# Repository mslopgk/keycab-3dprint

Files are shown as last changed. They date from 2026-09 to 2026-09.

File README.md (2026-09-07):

# keycab-3dprint

Parametric keycap modelling in Blender 5.2, driven programmatically.

## Layout

| Path | What it is |
| --- | --- |
| `tools/blender_mcp_ext/` | Blender extension exposing the `blender-mcp` socket protocol on `127.0.0.1:9876` |
| `tools/install_extension.py` | Copies the extension into Blender's user extension repo and enables it |
| `tools/serve_headless.py` | Runs the command server inside `blender --background` (no GUI, no manual Connect) |
| `tools/blender_server.ps1` | start / stop / restart / status / log for that headless server |
| `tools/blender_exec.py` | Send Python (or ask for scene info / a render) to the running Blender |
| `tools/mcp_client_test.py` | Protocol conformance + regression tests |
| `models/keycap.py` | Parametric Cherry MX 1u keycap: build, verify, export |
| `models/keycap_1u_r3.stl` | Printable output, literal millimetres |
| `renders/` | iso / front / bottom / underside previews |

## Setup, once

```powershell
python -m pip install uv                                    # provides uvx
blender --background --python tools\install_extension.py     # install the extension
claude mcp add blender -s user -e BLENDER_MCP_DISABLE_TELEMETRY=true `
  -e BLENDER_HOST=127.0.0.1 -e BLENDER_PORT=9876 -- uvx blender-mcp
```

`BLENDER_MCP_DISABLE_TELEMETRY=true` matters: upstream `blender-mcp` otherwise
uploads your prompt text and viewport screenshots to a remote endpoint
(`blender_mcp/telemetry.py`).

## Everyday use

```powershell
powershell -File tools\blender_server.ps1 start
python tools\blender_exec.py models\keycap.py     # rebuild, verify, export, render
python tools\blender_exec.py --scene-info
python tools\blender_exec.py --screenshot out.png --max-size 900
powershell -File tools\blender_server.ps1 stop
```

Restart the server after editing `tools/blender_mcp_ext/__init__.py` — the
headless entry point imports that module once at startup.

## Notes for this Blender build

Things that are specific to 5.2 here and cost real debugging time:

- **Legacy add-ons do not load.** `addon_utils.paths()` returns only
  `addons_core`; the user `scripts/addons` directory is no longer scanned. An
  add-on must ship as an extension with a `blender_manifest.toml`.
- **Only `BLENDER_EEVEE` is available** as a render engine — no Workbench, no
  Cycles. So there is no lighting-independent engine to fall back on, and
  previews have to bring their own lights.
- **`bpy.app.timers` never fire under `--background`.** Anything that relies on
  a timer to service work from another thread must pump on the main thread
  instead; that is what `serve_headless.py` does.
- **The default 0.1 m `clip_start` swallows millimetre-scale parts.** A camera
  framing an 18 mm keycap sits ~50 mm away, so the whole subject falls inside
  the near plane and renders as an empty background. The extension scales
  clipping to the subject.

## Keycap geometry

Modelled at 1 Blender unit = 1 mm, exported with `use_scene_unit=False` and
`global_scale=1.0`, so the STL carries literal millimetres.

Current parameters (all in `P` at the top of `models/keycap.py`):

| Parameter | Value | Note |
| --- | --- | --- |
| base | 18.0 × 18.0 mm | 1u spacing is 19.05 mm; the cap is undersized so neighbours don't rub |
| top plateau | 13.6 × 13.2 mm | Cherry-like R3, no front-to-back tilt |
| height | 8.6 mm | 8.55 mm after the dish |
| dish | 0.9 mm deep, R 24.65 mm | cylindrical, axis along X, so it scoops front-to-back |
| side wall | 1.35 mm | |
| roof | 1.5 mm | held constant under the dish, measured at three points |
| stem | ⌀5.5 mm | |
| MX cross | 4.1 × 1.35 mm, 4.0 mm deep | 1.30 grips hard but splits brittle filament; 1.40 goes loose |
| ribs | 4 × 1.0 mm, z 3.6 → 5.8 | start above the switch's top housing so they can't collide |

### Verification the build script performs

- watertight (no non-manifold edges, no loose verts) and normals outward
- roof thickness by ray-cast at three points clear of the stem and ribs
- ASCII cross-sections at z = 0.4 / 2.0 / 5.0 / 7.2 mm, which is the only way to
  confirm the cross socket and ribs — the cavity is unlit and invisible in a render
- the exported STL is re-read and its bounding box reported, to catch unit slips

A run that is not watertight still writes the STL for inspection but reports
`VERDICT: NOT PRINTABLE`.

### Not yet decided

Print orientation, tolerance for your specific printer/filament, row profile
(everything here is R3-ish and untilted), legends, and multi-unit sizes
(2u, shift, spacebar).

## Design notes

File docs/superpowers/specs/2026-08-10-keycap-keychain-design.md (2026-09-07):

# Keycap keychain with a mounted MX switch — design

Date: 2026-08-10
Status: approved, ready for implementation planning

## Goal

A keychain built around a real MX-compatible switch, with the existing
`models/keycap.py` keycap on top. The switch clicks, because the switch is
retained the way a keyboard retains it rather than glued into a shell.

## Decisions

Three questions were settled with the user up front. Each is recorded with the
option chosen, because they constrain everything downstream.

| Question | Chosen |
| --- | --- |
| Housing silhouette | Closed box — switch pins fully enclosed, nothing to snag in a pocket |
| Switch retention | Two pieces: MX latch retention on a 1.5 mm plate + removable snap-on bottom cap |
| Keyring attachment | Lug on one side with a 4.0 mm round hole |

Rejected and why:

- **Open plate frame** (bare 1.5 mm plate, no walls) — most keyboard-like, fastest
  to print, but leaves the pins exposed.
- **Press-fit pocket** (grip the 15.6 mm body, ignore the latches) — no tolerance
  headroom; 0.1 mm out and it either will not enter or does not hold.
- **One-piece closed box** — sturdiest and a single print, but with the bottom
  closed the latches cannot be reached, so the switch is in permanently.
- **Corner through-hole** / **strap slot** for the keyring — more compact, but a
  split ring in a corner hole rubs the keycap, and a strap slot cannot take a
  split ring at all.

## Parts

### A. Housing

| Parameter | Value | Note |
| --- | --- | --- |
| body footprint | 19.0 × 19.0 mm | pocket 15.8 + 2 × 1.6 wall |
| footprint incl. lug | 24.5 × 19.0 mm | |
| height | 11.0 mm | plate 1.5 + pocket 9.5 |
| top plate thickness | 1.5 mm | what the MX latches grab |
| plate opening | 14.0 × 14.0 mm, corner R0.5 | standard MX plate cutout |
| inner pocket | 15.8 × 15.8 mm | switch body 15.6 + 0.1 per side |
| pocket depth | 9.5 mm | below the plate underside |
| wall thickness | 1.6 mm | |
| latch relief | 1.0 mm deep groove below the opening, on **all four** sides | space for the latches to flex, whichever way the switch is rotated |
| lug | flat tab, 5.5 mm protrusion, 7.0 mm wide, 3.0 mm thick | see hole axis below |
| lug hole | 4.0 mm diameter, axis **vertical** (parallel to the box height), centre 2.0 mm out from the body face, 1.5 mm material around it | |

### Lug hole axis

Vertical, i.e. punched through the flat face of the tab rather than through its
edge. Two consequences, both wanted:

- Printed plate-down, a vertical hole needs no bridging. A horizontal hole would
  have to bridge across its own top.
- The keycap faces up when the keychain lies flat, instead of sideways.

The tab is deliberately offset to one side of the body, so the split ring never
touches the keycap. The assembly hangs slightly tilted because the centre of mass
is offset from the hole; this is accepted.

### B. Snap bottom cap

| Parameter | Value |
| --- | --- |
| plate | 19.0 × 19.0 × 1.2 mm, sits under the housing (assembled height 12.2 mm) |
| snap tongues | 4, one per side, 0.8 mm thick, rising into the pocket |
| undercut on housing inner wall | 0.6 mm, positioned 1.5 mm above the housing's bottom face |

### No individual pin holes

The pocket floor is flat and unbroken. The exact coordinates of the 5-pin
plastic posts and the metal pins are **not** reliably known here, and a hole
drilled at a wrong coordinate makes the part scrap. A generous flat pocket
accepts 3-pin and 5-pin switches alike without depending on those coordinates,
which also means one housing covers both switch types.

## Click travel

Nothing rises above plate level: the top face is a flat 19 × 19 plate with a
single 14 mm hole. The 18 mm keycap descends onto it unobstructed.

The argument for full 4 mm travel is structural, not arithmetic — the switch sits
in a standard 1.5 mm plate cutout, so its height relative to the plate is
identical to a keyboard's. No absolute stem or housing heights need to be known
or matched.

## Open tolerances, and how they get closed

Two values cannot be settled from specification alone:

1. **Effective plate thickness.** At a 0.28 mm layer height, a nominal 1.5 mm
   plate quantises to whatever the slicer rounds it to.
2. **Effective opening size.** Print shrinkage and extrusion width shift the
   14.0 mm cutout by an unknown fraction of a tenth.

Both are resolved empirically before the housing is printed:

**Coupon 1 — plate thickness.** One flat tile, 20 × 60 × 1.6 mm, three 20 × 20 mm
cells with plate thickness 1.4 / 1.5 / 1.6 mm at a fixed 14.0 mm opening, each
cell embossed with its thickness. Print flat, no support, roughly 4 minutes. The
cell where the switch latches with a clean click sets `plate_thickness`.

**Coupon 2 — opening (only if needed).** If every cell in coupon 1 is uniformly
loose or uniformly tight, a second coupon varies the opening 13.9 / 14.0 / 14.1
at the best thickness.

**Snap fit** will very likely need one or two iterations. The 0.6 mm undercut is a
starting value: too loose and the cap falls off, too tight and a tongue snaps.
Dial it on a coupon rather than on the full housing.

## Verification

The build script performs the same automated checks the keycap script does, for
both parts:

- watertight (no non-manifold edges, no loose vertices) and normals outward
- plate thickness measured by ray-cast at four points clear of the opening
- ASCII cross-sections at three heights — through the plate, through the pocket,
  and near the bottom face — confirming the 14.0 opening, the 15.8 pocket and the
  1.6 wall
- lug hole diameter measured
- exported STL re-read and its bounding box reported, to catch unit slips

A run that is not watertight still writes the STL for inspection but reports
`VERDICT: NOT PRINTABLE`.

## Print plan

| Part | Orientation | Support |
| --- | --- | --- |
| housing | plate face down on the bed, pocket opening upward | none |
| bottom cap | flat | none |
| coupons | flat | none |

Housing plate-down puts the flat plate face against the bed and grows the walls
upward, so the latch relief grooves and the pocket are never overhangs.

## Out of scope

Legends on the keycap, multi-unit sizes, a switch other than MX-compatible, and
any change to the existing keycap geometry. The keycap's own open question — the
1.35 mm cross slot fit — is tracked separately against the first keycap print and
does not affect this housing.

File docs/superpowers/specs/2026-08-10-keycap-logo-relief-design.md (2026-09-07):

# Raised church-wave logo on the keycap top — design

Date: 2026-08-10
Status: approved, ready for implementation planning

## Goal

Emboss the church-wave logo on the keycap top as a real raised relief, uniform
0.5 mm proud of the dished surface, printable with the existing 0.4 mm nozzle and
no support.

Source art: `C:\Users\user\Documents\카카오톡 받은 파일\church-wave-logo-03-minimal-line.svg`
(2048 × 2048 viewBox; its metadata records it as Recraft AI output).

## What the source file actually contains

The filename says "minimal-line" but the paths are **filled**, not stroked. The
navy disc is overlaid by large white shapes that carve the mark out of it, so the
region that would be embossed — navy minus white — is a set of thin strokes.
Ten paths import:

| Path role | Identified by | Action |
| --- | --- | --- |
| Background rect | its X extent equals the widest of all paths | discard |
| Navy disc, `rgb(25,8,76)` | darkest remaining path by luma | the figure |
| 2 white shapes | max dimension ≥ 2 % of the disc span | subtract from the disc |
| 3 pale slivers, `rgb(122,115,143)` / `rgb(193,190,201)` | max dimension < 2 % of the disc span; measured 0.0006–0.0061 Blender units | discard |

The slivers are anti-aliasing residue from the generator. At keycap scale they are
a few microns across and would only inject degenerate geometry into the booleans.

**Selection is by rule, never by object name.** The importer names paths
`Curve`, `Curve.001` … in file order, which is not a contract.

## Why the logo cannot be used as drawn

Measured at 12 mm diameter, sampled at 0.05 mm and eroded by the nozzle radius:

| | as drawn | +0.15 mm | +0.25 mm |
| --- | --- | --- | --- |
| ideal area | 19.45 mm² | 37.65 mm² | 49.55 mm² |
| stroke area lost to the nozzle | 8.55 mm² (44 %) | 1.62 mm² | **0.00 mm²** |
| gap area the nozzle fills in | — | 0.46 mm² | 0.59 mm² |
| fidelity | unusable | 94.5 % | **98.8 %** |

As drawn, strokes are ~0.2 mm — half a nozzle width — and 94 % of the logo area
is thinner than 0.4 mm. The cross and the outer ring disappear entirely; only the
thick lower-left wave arc survives. Scaling cannot fix it: the plateau is
13.6 × 13.2 mm, and full fidelity would need roughly 22–25 mm.

At **+0.15 mm** the cross's horizontal arms are still dropped. At **+0.25 mm**
nothing is dropped and the red merge artefacts are confined to sharp interior
junctions being rounded off. The mark reads as a bolder weight of itself.

**Decision: 12.0 mm diameter, strokes dilated by +0.25 mm.**

Caveat to carry into implementation: the erosion used a 4-connected (diamond)
structuring element, which is contained in the disc of the same radius, so it
removes slightly less than a true disc would. The survival figures are therefore
mildly optimistic and must be confirmed on the first print.

## Why the print orientation changes

The keycap is currently printed flipped, top face on the plate. A raised logo
cannot work that way, and the reason is geometric rather than a matter of taste.

The dish is a cylinder with its axis along X, so the top surface drops only in Y.
Measured on the built mesh: rim plane `z = 8.5522`, dish centre `z = 7.7000`.
For a logo whose top is one flat plane at the rim height, the relief available is:

| position | relief |
| --- | --- |
| along X, any offset | 0.852 mm |
| y = ±3 | 0.661 mm |
| y = ±5 | 0.336 mm |
| y = ±6 | **0.111 mm** |

0.111 mm is below both the 0.28 mm layer height and the 0.20 mm first layer, so
the ring's top and bottom would vanish while its left and right stood 0.852 mm
proud — a 7.7× asymmetry.

Giving the logo a dish-parallel top instead makes the relief uniform, but that
surface sits below the bed plane once the part is flipped, which is impossible.
**Uniform relief and flipped printing are mutually exclusive.**

**Decision: print the logo variant right side up** — bottom rim and stem base on
the plate, logo uppermost.

Right side up, the only surface that would need support is the cavity ceiling,
which currently runs parallel to the dish at about 6.4° from horizontal.
**Decision: make the ceiling flat at `z = 6.2`** so it becomes a ~15 mm bridge,
which needs no support. The cost is a roof that is no longer a constant
thickness: 1.5 mm at the centre, 2.24 mm at the plateau edge. For a keychain the
extra material does not matter.

Everything else prints in its best orientation: the outer walls narrow going up
(self-supporting), the stem grows from the plate, the ribs are ~3 mm bridges, the
cross socket's roof is a trivial bridge, and the visible top surface is printed
last.

## Separate variant, not a modification

The plain keycap stays exactly as it is. The logo version is a second output.

This is not tidiness: Task 2 of `docs/superpowers/plans/2026-08-10-mx-switch-keychain.md`
uses the current STL hashes (`f567510240023cb5a7808314c5a7bf60` and
`51c9fe26924c15bf2439d854c985276d`) as its refactor regression gate. Changing the
existing outputs would break that check.

- `models/keycap_1u_r3.stl` — unchanged, flipped-print orientation, no logo
- `models/keycap_1u_r3_logo.stl` — flat ceiling, right side up, logo

The logo and the flat ceiling are enabled together by one parameter block; the
ceiling shape follows from the print orientation, which follows from the logo.

## Construction

The relief is cut from between two copies of the dish cylinder rather than
extruded to a fixed height, which is what makes the relief uniform:

```
logo_2d    = disc − white_cutters, dilated +0.25 mm, scaled to 12.0 mm
logo_prism = logo_2d extruded well past both surfaces
logo_solid = logo_prism ∩ dish_cutter − dish_cutter_raised_by_0.5mm
keycap     = keycap ∪ logo_solid
```

`dish_cutter` is the same cylinder the keycap already uses for the dish, so its
lower boundary *is* the top surface. Raising a second copy by 0.5 mm gives the
logo's top surface, parallel by construction.

Dilation: try `Curve.offset` on the composed 2D curve first and measure the
resulting stroke widths. If it does not offset the fill correctly, fall back to
rasterising at 0.02 mm and tracing contours — 20× finer than the 0.4 mm the
printer can resolve, so the faceting is invisible in the print.

## Accepted consequence: the logo crests the rim

At y = ±6 the dish surface is at 8.4416, so the logo top reaches 8.9416 — about
0.39 mm above the rim plane at 8.5522. The ring's top and bottom therefore stand
proud of the keycap's top edge, giving a medallion look from the side, and the
part's height becomes 8.94 mm instead of 8.5522 mm.

Printing right side up means this costs nothing technically; it is purely
appearance, and it is accepted. The alternative — shrinking the logo to 8 mm so it
tucks under the rim — was rejected because the stroke-width evidence was gathered
at 12 mm and would have to be redone.

## Verification

Same automated gates as the keycap, plus logo-specific ones:

- watertight (no non-manifold edges, no loose vertices) and normals outward
- relief height ray-cast at eight points spread around the logo; every one must
  read 0.5 mm ± 0.02 mm — this is the check that would have caught the flat-top
  defect
- minimum stroke width on the **final** mesh, measured by rasterising and
  eroding; must be ≥ 0.45 mm, giving margin over the 0.4 mm nozzle
- ceiling flatness: ray-cast up from inside the cavity at several points, all
  returning the same z
- roof thickness measured at the centre (expect 1.5 mm) and at the plateau edge
  (expect 2.24 mm)
- ASCII cross-section just below the top surface, showing the logo outline
- exported STL re-read; bounding box must be 18.0 × 18.0 × 8.94 mm
- top-down render for a visual check against the reference art

A run that fails watertightness or the relief-height check still writes the STL
for inspection but reports `VERDICT: NOT PRINTABLE`.

## Print settings

Right side up, no support, brim 3 mm, 0.28 mm layers, textured PEI plate at
65 °C, sliced through `tools/slice_part.ps1` from the keychain plan.

## Out of scope

Text legends, a second filament colour for the logo, any change to the plain
keycap or to the switch housing, and re-cutting the source SVG by hand.

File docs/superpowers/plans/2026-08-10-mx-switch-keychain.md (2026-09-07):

# MX Switch Keychain Implementation Plan

> **For agentic workers:** REQUIRED SUB-SKILL: Use superpowers:subagent-driven-development (recommended) or superpowers:executing-plans to implement this plan task-by-task. Steps use checkbox (`- [ ]`) syntax for tracking.

**Goal:** Build a two-piece 3D-printable closed-box housing that retains a real MX-compatible switch on a 1.5 mm plate cutout, with a keyring lug and a removable snap-on bottom cap, plus fit coupons to settle the two unknown tolerances first.

**Architecture:** Geometry helpers currently private to `models/keycap.py` get extracted into an importable `models/mxgeom.py`, then the housing, the cap, and the coupons are three build scripts on top of it. Everything runs inside a headless Blender through the existing socket server; there is no pytest, so "tests" are assertion scripts that run in Blender and exit non-zero on failure.

**Tech Stack:** Blender 5.2 `bpy`/`bmesh` (1 Blender unit == 1 mm), Python 3.12 on the host, the project's own `tools/blender_exec.py` socket client, OrcaSlicer 2.4.2 portable CLI, Bambu Lab A1 mini over LAN.

## Global Constraints

- Model at **1 Blender unit == 1 mm**. Export STL with `global_scale=1.0` and `use_scene_unit=False`.
- Every exported part must be **watertight** (zero non-manifold edges, zero loose vertices) with **outward normals** (`signed_volume > 0`). A part failing this still exports for inspection but the script must report `VERDICT: NOT PRINTABLE`.
- **No individual pin holes** in the pocket floor. The floor is flat and unbroken.
- Housing dimensions, verbatim from the spec: body `19.0 × 19.0 mm`; footprint incl. lug `24.5 × 19.0 mm`; height `11.0 mm`; plate thickness `1.5 mm`; plate opening `14.0 × 14.0 mm` corner `R0.5`; pocket `15.8 × 15.8 mm`; pocket depth `9.5 mm`; wall `1.6 mm`; latch relief `1.0 mm` deep on **all four** sides; lug tab `5.5 mm` protrusion × `7.0 mm` wide × `3.0 mm` thick; lug hole `4.0 mm` diameter, **vertical axis**, centre `2.0 mm` out from the body face, `1.5 mm` material around it.
- Bottom cap, verbatim from the spec: `19.0 × 19.0 × 1.2 mm` plate sitting **under** the housing (assembled height `12.2 mm`); `4` snap tongues, one per side, `0.8 mm` thick; housing inner-wall undercut `0.6 mm`, positioned `1.5 mm` above the housing's bottom face.
- Coupon 1, verbatim from the spec: one flat tile `20 × 60 × 1.6 mm`, three `20 × 20 mm` cells, plate thickness `1.4 / 1.5 / 1.6 mm`, opening fixed at `14.0 mm`, each cell embossed with its thickness.
- Print orientation: housing **plate face down**, cap **flat**, coupons **flat**. No support on any part.
- Do not delete or overwrite anything on the printer's SD card.

---

### Task 1: Give Blender-side scripts a `__file__` so they can import siblings

The addon's `execute_code` builds its namespace with `__name__` but no `__file__` (`tools/blender_mcp_ext/__init__.py:140-146`). A script sent through the socket therefore cannot locate its own directory, so `models/switch_housing.py` cannot `import mxgeom`. Fix it host-side in the client by prepending a preamble, which keeps the wire protocol unchanged and needs no addon edit or server restart.

**Files:**
- Modify: `tools/blender_exec.py` (the `main()` branch that reads a script file)
- Create: `tests/blender/test_script_context.py`

**Interfaces:**
- Consumes: nothing.
- Produces: a guarantee that any file executed via `python tools/blender_exec.py <path>` sees `__file__` set to the script's absolute path, and that `os.path.dirname(__file__)` is on `sys.path`.

- [ ] **Step 1: Write the failing test**

Create `tests/blender/test_script_context.py`:

```python
"""Runs inside Blender. Exits non-zero if the script context is missing."""

import os
import sys

failures = []

def check(label, condition, detail=""):
    print(f"{'PASS' if condition else 'FAIL'}  {label}" + (f" -- {detail}" if detail else ""))
    if not condition:
        failures.append(label)

check("__file__ is defined", "__file__" in globals(), repr(globals().get("__file__")))

path = globals().get("__file__", "")
check("__file__ is absolute", bool(path) and os.path.isabs(path), path)
check("__file__ basename matches", os.path.basename(path) == "test_script_context.py", path)
check("__file__ exists on disk", bool(path) and os.path.exists(path), path)
check("own directory is importable", os.path.dirname(path) in sys.path, os.path.dirname(path))

print(f"\n{'ALL CHECKS PASSED' if not failures else str(len(failures)) + ' FAILED: ' + str(failures)}")
if failures:
    raise SystemExit(1)
```

- [ ] **Step 2: Run test to verify it fails**

```bash
powershell -File tools/blender_server.ps1 start
python tools/blender_exec.py tests/blender/test_script_context.py
```

Expected: `FAIL  __file__ is defined -- None` and the remaining four checks also FAIL, because `blender_exec.py` currently sends only the file's bytes.

- [ ] **Step 3: Write minimal implementation**

In `tools/blender_exec.py`, replace the branch that reads a script from disk:

```python
        elif args.script:
            with open(args.script, "r", encoding="utf-8") as handle:
                code = handle.read()
```

with:

```python
        elif args.script:
            with open(args.script, "r", encoding="utf-8") as handle:
                code = handle.read()
            # execute_code has no notion of a file, so the script cannot find its
            # own directory and cannot import a sibling module. Supply both.
            script_path = os.path.abspath(args.script)
            preamble = (
                "import os, sys\n"
                f"__file__ = {script_path!r}\n"
                f"_d = os.path.dirname({script_path!r})\n"
                "sys.path.insert(0, _d) if _d not in sys.path else None\n"
                "del _d\n"
            )
            code = preamble + code
```

- [ ] **Step 4: Run test to verify it passes**

```bash
python tools/blender_exec.py tests/blender/test_script_context.py
```

Expected: five `PASS` lines then `ALL CHECKS PASSED`, exit code 0.

- [ ] **Step 5: Confirm nothing regressed for inline code and the existing suite**

```bash
python tools/blender_exec.py -c "print('inline still works')"
python tools/mcp_client_test.py
```

Expected: `inline still works`; then `ALL CHECKS PASSED` from the protocol suite. The preamble is only added on the file branch, so `-c` is untouched.

- [ ] **Step 6: Commit**

```bash
git add tools/blender_exec.py tests/blender/test_script_context.py
git commit -m "feat: give Blender-side scripts __file__ and an importable directory"
```

---

### Task 2: Extract shared geometry into `models/mxgeom.py`

`models/keycap.py` defines every helper the housing needs but keeps them file-local, and it calls `main()` at module level, so importing it would rebuild and re-export the keycap. Extract the reusable half into a module that has no side effects at import.

**Files:**
- Create: `models/mxgeom.py`
- Modify: `models/keycap.py` (delete the extracted definitions, import them instead)
- Create: `tests/blender/test_mxgeom.py`

**Interfaces:**
- Consumes: Task 1's `sys.path` injection, so `import mxgeom` resolves from `models/`.
- Produces, all in `mxgeom`, signatures unchanged from their current definitions in `keycap.py`:
  - `rounded_rect(width, depth, radius, segments) -> list[tuple[float, float]]`
  - `make_loft(name, bottom_outline, z0, top_outline, z1) -> bpy.types.Object`
  - `make_box(name, size, location) -> bpy.types.Object`
  - `make_cylinder(name, radius, depth, location, segments, axis="Z") -> bpy.types.Object`
  - `boolean(target, tool, operation, keep_tool=False) -> bpy.types.Object`
  - `duplicate(obj, name) -> bpy.types.Object`
  - `bevel_top_rim(obj, z_top, offset, segments) -> int`
  - `mesh_report(obj) -> dict`
  - `reset_scene() -> None`
  - `point_inside(obj, point) -> bool`
  - `export_stl(obj, path) -> str`
  - `verify_stl_millimetres(path) -> dict`
  - And one new helper, generalised from `keycap.cross_sections` so it no longer takes the keycap's `P` dict:
    `cross_sections(obj, half_extent, heights, step=0.5) -> dict[str, list[str]]`

- [ ] **Step 1: Write the failing test**

Create `tests/blender/test_mxgeom.py`:

```python
"""Runs inside Blender. Checks the extracted helpers behave as before."""

import mxgeom

failures = []

def check(label, condition, detail=""):
    print(f"{'PASS' if condition else 'FAIL'}  {label}" + (f" -- {detail}" if detail else ""))
    if not condition:
        failures.append(label)

mxgeom.reset_scene()

# rounded_rect: 4 corners * (segments + 1) points, all inside the half extents.
pts = mxgeom.rounded_rect(19.0, 19.0, 1.0, 8)
check("rounded_rect point count", len(pts) == 4 * 9, str(len(pts)))
check("rounded_rect stays in bounds",
      max(abs(x) for x, _ in pts) <= 9.5 + 1e-6 and max(abs(y) for _, y in pts) <= 9.5 + 1e-6)

# make_box: a 19 x 19 x 1.2 plate centred at z = 0.6 spans z 0..1.2.
box = mxgeom.make_box("T_Box", (19.0, 19.0, 1.2), (0.0, 0.0, 0.6))
check("make_box dimensions", [round(v, 4) for v in box.dimensions] == [19.0, 19.0, 1.2],
      str([round(v, 4) for v in box.dimensions]))
report = mxgeom.mesh_report(box)
check("make_box watertight", report["watertight"], str(report))
check("make_box normals outward", report["normals_outward"], str(report))
check("make_box volume", abs(report["signed_volume_mm3"] - 19.0 * 19.0 * 1.2) < 1e-3,
      str(report["signed_volume_mm3"]))

# point_inside: centre is solid, a point outside the slab is not.
check("point_inside centre", mxgeom.point_inside(box, (0.0, 0.0, 0.6)) is True)
check("point_inside above", mxgeom.point_inside(box, (0.0, 0.0, 5.0)) is False)

# boolean DIFFERENCE punches a hole that point_inside can see.
tool = mxgeom.make_cylinder("T_Cut", 2.0, 10.0, (0.0, 0.0, 0.6), 48)
mxgeom.boolean(box, tool, "DIFFERENCE")
check("boolean cut removes centre", mxgeom.point_inside(box, (0.0, 0.0, 0.6)) is False)
check("boolean cut keeps edge", mxgeom.point_inside(box, (8.0, 8.0, 0.6)) is True)
check("boolean result watertight", mxgeom.mesh_report(box)["watertight"])

# cross_sections takes a half extent now, not the keycap parameter dict.
sections = mxgeom.cross_sections(box, 10.0, heights=(0.6,), step=1.0)
rows = sections["z=0.6"]
check("cross_sections row count", len(rows) == 21, str(len(rows)))
check("cross_sections centre is air", rows[len(rows) // 2][len(rows) // 2] == ".",
      rows[len(rows) // 2])

print(f"\n{'ALL CHECKS PASSED' if not failures else str(len(failures)) + ' FAILED: ' + str(failures)}")
if failures:
    raise SystemExit(1)
```

- [ ] **Step 2: Run test to verify it fails**

```bash
python tools/blender_exec.py tests/blender/test_mxgeom.py
```

Expected: FAIL with `ModuleNotFoundError: No module named 'mxgeom'`.

- [ ] **Step 3: Create `models/mxgeom.py`**

Move — do not copy — these definitions out of `models/keycap.py` into a new `models/mxgeom.py`, keeping their bodies byte-identical: `rounded_rect`, `make_loft`, `bevel_top_rim`, `make_box`, `make_cylinder`, `boolean`, `duplicate`, `mesh_report`, `reset_scene`, `point_inside`, `export_stl`, `verify_stl_millimetres`. Give the module this header and imports, and no module-level side effects:

```python
"""Shared geometry and verification helpers for the keycab-3dprint models.

Modelled at 1 Blender unit == 1 mm throughout. Import-safe: defining anything
here must never touch the scene, so build scripts can import it freely.
"""

import math
import os
import struct

import bmesh
import bpy
import mathutils
```

Then add the generalised `cross_sections`, replacing the keycap-specific one:

```python
def cross_sections(obj, half_extent, heights, step=0.5):
    """ASCII slices through the solid, '#' for material and '.' for air.

    Takes an explicit half extent rather than a parameter dict so any part can
    use it. Rows print with +Y at the top and +X to the right.
    """
    coords = []
    value = -half_extent
    while value <= half_extent + 1e-9:
        coords.append(round(value, 3))
        value += step

    sections = {}
    for z in heights:
        rows = []
        for y in reversed(coords):
            rows.append("".join(
                "#" if point_inside(obj, (x, y, z)) else "."
                for x in coords
            ))
        sections[f"z={z}"] = rows
    return sections
```

- [ ] **Step 4: Repoint `models/keycap.py` at the module**

Replace `keycap.py`'s now-deleted definitions with an import, and delete its local `cross_sections`:

```python
import mxgeom
from mxgeom import (
    bevel_top_rim, boolean, cross_sections, duplicate, export_stl, make_box,
    make_cylinder, make_loft, mesh_report, point_inside, reset_scene,
    rounded_rect, verify_stl_millimetres,
)
```

Update the one call site that passed the parameter dict. In `main()`, change:

```python
    sections = cross_sections(keycap, P, heights=(0.4, 2.0, 5.0, 7.2))
```

to:

```python
    sections = cross_sections(keycap, P["base_width"] / 2.0 + 0.25,
                              heights=(0.4, 2.0, 5.0, 7.2))
```

Leave `dish_radius`, `build_keycap`, `measure_top_thickness`, `render_views`, `main`, `P` and `REPORT` in `keycap.py` — they are keycap-specific.

- [ ] **Step 5: Run the helper test to verify it passes**

```bash
python tools/blender_exec.py tests/blender/test_mxgeom.py
```

Expected: every check `PASS`, then `ALL CHECKS PASSED`, exit code 0.

- [ ] **Step 6: Prove the keycap is byte-identical after the refactor**

The extraction must not change geometry, so re-running the keycap build must reproduce the exact same STL.

```bash
python tools/blender_exec.py models/keycap.py
md5sum models/keycap_1u_r3.stl
```

Expected: `KEYCAP_REPORT_START` … `"VERDICT": "printable"`, `non_manifold_edges: 0`, and the hash exactly `f567510240023cb5a7808314c5a7bf60` (45184 bytes). Then re-run the print-orientation export and check its hash too:

```bash
"/c/Program Files/Blender Foundation/Blender 5.2/blender.exe" --background models/keycap_1u_r3.blend --python models/export_printready.py
md5sum models/keycap_1u_r3_printready.stl
```

Expected: `51c9fe26924c15bf2439d854c985276d` (45184 bytes). **If either hash differs, the extraction changed behaviour — stop and diff the moved functions rather than accepting the new hash.**

- [ ] **Step 7: Commit**

```bash
git add models/mxgeom.py models/keycap.py tests/blender/test_mxgeom.py
git commit -m "refactor: extract shared geometry helpers into models/mxgeom.py"
```

---

### Task 3: Housing body — plate, opening and pocket

Build the housing's core solid: a 19 × 19 × 11 block, a 14 × 14 opening through the 1.5 mm top plate, and a 15.8 × 15.8 × 9.5 pocket open at the bottom. Lug and latch relief come in Task 4; the cap comes in Task 5.

**Files:**
- Create: `models/switch_housing.py`
- Create: `tests/blender/test_housing_body.py`

**Interfaces:**
- Consumes: `mxgeom.rounded_rect`, `make_box`, `boolean`, `mesh_report`, `reset_scene`, `point_inside`, `cross_sections`, `export_stl`, `verify_stl_millimetres`.
- Produces:
  - `models/switch_housing.py` module-level `H` dict holding every dimension by the spec's names: `body_width`, `body_depth`, `height`, `plate_thickness`, `opening`, `opening_corner_r`, `pocket`, `pocket_depth`, `wall`, `latch_relief_depth`, `lug_protrusion`, `lug_width`, `lug_thickness`, `lug_hole_diameter`, `lug_hole_offset`, `cap_thickness`, `cap_tongue_thickness`, `undercut_depth`, `undercut_z`, `corner_segments`.
  - `build_housing(h) -> bpy.types.Object` named `Switch_Housing`.
  - `housing_report(obj, h) -> dict` with keys `dimensions_mm`, `mesh`, `plate_thickness_probe`, `opening_probe`, `pocket_probe`, `VERDICT`.

- [ ] **Step 1: Write the failing test**

Create `tests/blender/test_housing_body.py`:

```python
"""Runs inside Blender. Verifies the housing's plate, opening and pocket."""

import mxgeom
import switch_housing

failures = []

def check(label, condition, detail=""):
    print(f"{'PASS' if condition else 'FAIL'}  {label}" + (f" -- {detail}" if detail else ""))
    if not condition:
        failures.append(label)

mxgeom.reset_scene()
h = dict(switch_housing.H)
# Task 3 builds the core solid only; lug and relief are Task 4.
h["lug_protrusion"] = 0.0
h["latch_relief_depth"] = 0.0
obj = switch_housing.build_housing(h)

dims = [round(v, 4) for v in obj.dimensions]
check("footprint without lug is 19 x 19", dims[0] == 19.0 and dims[1] == 19.0, str(dims))
check("height is 11.0", dims[2] == 11.0, str(dims))

report = mxgeom.mesh_report(obj)
check("watertight", report["watertight"], str(report))
check("normals outward", report["normals_outward"], str(report))

plate_top = h["height"]                      # 11.0
plate_bottom = h["height"] - h["plate_thickness"]   # 9.5

# Plate: solid at its own level away from the opening, air inside the opening.
check("plate is solid at the edge",
      mxgeom.point_inside(obj, (8.5, 8.5, plate_top - 0.5)) is True)
check("opening is air at plate level",
      mxgeom.point_inside(obj, (0.0, 0.0, plate_top - 0.5)) is False)
check("opening is 14 wide: inside at 6.8",
      mxgeom.point_inside(obj, (6.8, 0.0, plate_top - 0.5)) is False)
check("opening is 14 wide: material at 7.2",
      mxgeom.point_inside(obj, (7.2, 0.0, plate_top - 0.5)) is True)

# Pocket: air in the middle, wall material outside 15.8/2 = 7.9.
check("pocket is air", mxgeom.point_inside(obj, (0.0, 0.0, 5.0)) is False)
check("pocket is 15.8 wide: inside at 7.7",
      mxgeom.point_inside(obj, (7.7, 0.0, 5.0)) is False)
check("wall is material at 8.5", mxgeom.point_inside(obj, (8.5, 0.0, 5.0)) is True)

# body_width, pocket and wall must agree, or the wall thickness is a fiction.
bad = dict(h)
bad["pocket"] = 16.2          # would imply a 1.4 wall, not 1.6
raised = False
try:
    switch_housing.build_housing(bad)
except ValueError:
    raised = True
check("inconsistent wall raises ValueError", raised)

# Bottom face must be open, not skinned over.
check("bottom is open", mxgeom.point_inside(obj, (0.0, 0.0, 0.2)) is False)

# Ray-cast the plate thickness at a point clear of the opening.
probe = switch_housing.housing_report(obj, h)["plate_thickness_probe"]
check("plate measures 1.5 thick",
      any(abs(v - 1.5) < 0.02 for v in probe.values() if isinstance(v, float)),
      str(probe))

print(f"\n{'ALL CHECKS PASSED' if not failures else str(len(failures)) + ' FAILED: ' + str(failures)}")
if failures:
    raise SystemExit(1)
```

- [ ] **Step 2: Run test to verify it fails**

```bash
python tools/blender_exec.py tests/blender/test_housing_body.py
```

Expected: FAIL with `ModuleNotFoundError: No module named 'switch_housing'`.

- [ ] **Step 3: Write minimal implementation**

Create `models/switch_housing.py`:

```python
"""Two-piece closed-box housing that retains an MX-compatible switch.

Spec: docs/superpowers/specs/2026-08-10-keycap-keychain-design.md

Modelled at 1 Blender unit == 1 mm. The switch is held the way a keyboard holds
it -- latches gripping the underside of a 1.5 mm plate -- so click travel matches
a keyboard by construction rather than by matching absolute stem heights.
"""

import json
import os

import bmesh
import bpy
import mathutils

import mxgeom
from mxgeom import (
    boolean, cross_sections, export_stl, make_box, make_cylinder, make_loft,
    mesh_report, point_inside, reset_scene, rounded_rect, verify_stl_millimetres,
)

H = {
    "body_width": 19.0,
    "body_depth": 19.0,
    "height": 11.0,
    "plate_thickness": 1.5,
    "opening": 14.0,
    "opening_corner_r": 0.5,
    "pocket": 15.8,
    "pocket_depth": 9.5,
    "wall": 1.6,
    "latch_relief_depth": 1.0,
    "lug_protrusion": 5.5,
    "lug_width": 7.0,
    "lug_thickness": 3.0,
    "lug_hole_diameter": 4.0,
    "lug_hole_offset": 2.0,
    "cap_thickness": 1.2,
    "cap_tongue_thickness": 0.8,
    "undercut_depth": 0.6,
    "undercut_z": 1.5,
    "corner_segments": 8,
}

def build_housing(h):
    """Core solid: block, plate opening, pocket. Lug/relief handled by Task 4."""
    # body_width, pocket and wall are three numbers describing two independent
    # dimensions, so they can silently disagree. Fail loudly instead.
    derived_wall = (h["body_width"] - h["pocket"]) / 2.0
    if abs(derived_wall - h["wall"]) > 1e-6:
        raise ValueError(
            f"wall mismatch: body_width {h['body_width']} - pocket {h['pocket']} "
            f"implies a {derived_wall} wall, but wall is set to {h['wall']}"
        )

    body = make_box(
        "Switch_Housing",
        (h["body_width"], h["body_depth"], h["height"]),
        (0.0, 0.0, h["height"] / 2.0),
    )

    # Pocket, open at the bottom. Extends below z=0 so the underside is genuinely
    # open rather than skinned, the same trick the keycap cavity uses.
    pocket_top = h["height"] - h["plate_thickness"]
    pocket = make_box(
        "Pocket",
        (h["pocket"], h["pocket"], h["pocket_depth"] + 2.0),
        (0.0, 0.0, pocket_top - (h["pocket_depth"] + 2.0) / 2.0 + 1.0),
    )
    boolean(body, pocket, "DIFFERENCE")

    # Plate opening: rounded-square prism through the plate only, overshooting
    # both faces so no coplanar faces meet the plate surfaces.
    outline = rounded_rect(h["opening"], h["opening"], h["opening_corner_r"],
                           h["corner_segments"])
    opening = make_loft("Opening", outline, pocket_top - 1.0, outline, h["height"] + 1.0)
    boolean(body, opening, "DIFFERENCE")

    body.name = "Switch_Housing"
    body.data.name = "Switch_Housing"
    return body

def measure_plate_thickness(obj, h):
    """Ray-cast down through the plate at four points clear of the opening."""
    results = {}
    for label, x, y in (("front_left", -8.2, -8.2), ("front_right", 8.2, -8.2),
                        ("back_left", -8.2, 8.2), ("back_right", 8.2, 8.2)):
        origin = mathutils.Vector((x, y, h["height"] + 5.0))
        direction = mathutils.Vector((0.0, 0.0, -1.0))
        hits = []
        cursor = origin.copy()
        for _ in range(6):
            hit, location, _n, _i = obj.ray_cast(cursor, direction)
            if not hit:
                break
            hits.append(round(location.z, 4))
            cursor = location + direction * 1e-4
        results[f"{label}_hits"] = hits
        if len(hits) >= 2:
            results[label] = round(hits[0] - hits[1], 4)
    return results

def _span(obj, z, axis):
    """Width of the air gap through the centre at height z, sampled at 0.05mm."""
    step = 0.05
    limit = 12.0
    positive = 0.0
    value = 0.0
    while value <= limit:
        point = (value, 0.0, z) if axis == "x" else (0.0, value, z)
        if point_inside(obj, point):
            break
        positive = value
        value += step
    return round(positive * 2.0, 3)

def housing_report(obj, h):
    plate_top = h["height"]
    report = {
        "dimensions_mm": [round(v, 4) for v in obj.dimensions],
        "mesh": mesh_report(obj),
        "plate_thickness_probe": measure_plate_thickness(obj, h),
        "opening_probe": {
            "x_span_mm": _span(obj, plate_top - h["plate_thickness"] / 2.0, "x"),
            "y_span_mm": _span(obj, plate_top - h["plate_thickness"] / 2.0, "y"),
        },
        "pocket_probe": {
            "x_span_mm": _span(obj, h["pocket_depth"] / 2.0, "x"),
            "y_span_mm": _span(obj, h["pocket_depth"] / 2.0, "y"),
        },
    }
    mesh = report["mesh"]
    if not mesh["watertight"]:
        report["VERDICT"] = "NOT PRINTABLE - mesh is not watertight"
    elif not mesh["normals_outward"]:
        report["VERDICT"] = "NOT PRINTABLE - normals point inward"
    else:
        report["VERDICT"] = "printable"
    return report

def main():
    project = os.environ.get(
        "KEYCAB_PROJECT", r"C:\Users\user\orca\projects\keycab-3dprint"
    )
    reset_scene()
    scene = bpy.context.scene
    scene.unit_settings.system = "METRIC"
    scene.unit_settings.scale_length = 0.001
    scene.unit_settings.length_unit = "MILLIMETERS"

    housing = build_housing(H)
    report = housing_report(housing, H)
    report["parameters"] = H

    stl = os.path.join(project, "models", "switch_housing.stl")
    export_stl(housing, stl)
    report["stl"] = verify_stl_millimetres(stl)

    print("HOUSING_REPORT_START")
    print(json.dumps(report, indent=2))
    print("HOUSING_REPORT_END")

    sections = cross_sections(housing, H["body_width"] / 2.0 + 0.25,
                              heights=(0.5, 5.0, 10.2))
    print("\nCROSS SECTIONS  ('#' = plastic, '.' = air, 0.5mm grid, +Y up, +X right)")
    for label, rows in sections.items():
        print(f"\n--- {label} mm ---")
        for row in rows:
            print("   " + row)

if __name__ == "__blender_mcp__":
    main()
```

- [ ] **Step 4: Run test to verify it passes**

```bash
python tools/blender_exec.py tests/blender/test_housing_body.py
```

Expected: every check `PASS`, then `ALL CHECKS PASSED`.

If `watertight` fails, the cause is almost certainly a coplanar face where the pocket or opening cutter lands exactly on a housing surface — the same failure mode that produced 10 non-manifold edges in the keycap. Widen the offending cutter's overshoot; do not "fix" it by ignoring the check.

- [ ] **Step 5: Run the full build and read the cross-sections**

```bash
python tools/blender_exec.py models/switch_housing.py
```

Expected: `"VERDICT": "printable"`, `non_manifold_edges: 0`, `opening_probe` spans ≈ `14.0`, `pocket_probe` spans ≈ `15.8`, `stl.size_mm` ≈ `[19.0, 19.0, 11.0]`. The `z=10.2` section shows a 14 mm square hole in a solid plate; `z=5.0` shows a 15.8 mm pocket ringed by 1.6 mm wall; `z=0.5` looks the same as `z=5.0`.

- [ ] **Step 6: Commit**

```bash
git add models/switch_housing.py tests/blender/test_housing_body.py
git commit -m "feat: housing body with 1.5mm plate, 14mm MX opening and 15.8mm pocket"
```

---

### Task 4: Latch relief on all four sides, and the keyring lug

**Files:**
- Modify: `models/switch_housing.py` (extend `build_housing`)
- Create: `tests/blender/test_housing_lug_relief.py`

**Interfaces:**
- Consumes: Task 3's `build_housing(h)`, `H`, `housing_report(obj, h)`.
- Produces: `build_housing` now honours `h["latch_relief_depth"]` and `h["lug_protrusion"]`; `housing_report` gains a `lug_hole_probe` key with `diameter_mm`.

- [ ] **Step 1: Write the failing test**

Create `tests/blender/test_housing_lug_relief.py`:

```python
"""Runs inside Blender. Verifies latch relief grooves and the keyring lug."""

import mxgeom
import switch_housing

failures = []

def check(label, condition, detail=""):
    print(f"{'PASS' if condition else 'FAIL'}  {label}" + (f" -- {detail}" if detail else ""))
    if not condition:
        failures.append(label)

mxgeom.reset_scene()
h = dict(switch_housing.H)
obj = switch_housing.build_housing(h)

dims = [round(v, 4) for v in obj.dimensions]
check("footprint with lug is 24.5 x 19", dims[0] == 24.5 and dims[1] == 19.0, str(dims))
check("height still 11.0", dims[2] == 11.0, str(dims))

report = mxgeom.mesh_report(obj)
check("watertight", report["watertight"], str(report))
check("normals outward", report["normals_outward"], str(report))

plate_bottom = h["height"] - h["plate_thickness"]     # 9.5
relief_z = plate_bottom - h["latch_relief_depth"] / 2.0   # 9.0

# Relief widens the opening below the plate on all four sides, so a point that
# is material at plate level is air one millimetre lower.
for label, x, y in (("+X", 7.2, 0.0), ("-X", -7.2, 0.0),
                    ("+Y", 0.0, 7.2), ("-Y", 0.0, -7.2)):
    check(f"relief present on {label}",
          mxgeom.point_inside(obj, (x, y, h["height"] - 0.5)) is True
          and mxgeom.point_inside(obj, (x, y, relief_z)) is False,
          f"plate={mxgeom.point_inside(obj, (x, y, h['height'] - 0.5))} "
          f"relief={mxgeom.point_inside(obj, (x, y, relief_z))}")

check("relief does not breach the wall",
      mxgeom.point_inside(obj, (8.6, 0.0, relief_z)) is True)

# Lug sits on -X, centred on the body height, hole axis vertical.
lug_x = -(h["body_width"] / 2.0 + h["lug_hole_offset"])   # -11.5
lug_z = h["height"] / 2.0                                  # 5.5
check("lug material exists", mxgeom.point_inside(obj, (lug_x, 3.0, lug_z)) is True)
check("lug hole is air at its centre",
      mxgeom.point_inside(obj, (lug_x, 0.0, lug_z)) is False)
check("lug hole is 4mm: air at 1.8 from centre",
      mxgeom.point_inside(obj, (lug_x, 1.8, lug_z)) is False)
check("lug hole is 4mm: material at 2.2 from centre",
      mxgeom.point_inside(obj, (lug_x, 2.2, lug_z)) is True)

# Vertical axis: the hole is air all the way through the tab's 3mm thickness,
# and solid above and below it.
check("hole runs vertically through the tab",
      mxgeom.point_inside(obj, (lug_x, 0.0, lug_z + 1.0)) is False
      and mxgeom.point_inside(obj, (lug_x, 0.0, lug_z - 1.0)) is False)
check("tab has material above the hole",
      mxgeom.point_inside(obj, (lug_x, 3.0, lug_z + 1.0)) is True)

probe = switch_housing.housing_report(obj, h)["lug_hole_probe"]
check("measured hole diameter is 4.0",
      abs(probe["diameter_mm"] - 4.0) < 0.15, str(probe))

print(f"\n{'ALL CHECKS PASSED' if not failures else str(len(failures)) + ' FAILED: ' + str(failures)}")
if failures:
    raise SystemExit(1)
```

- [ ] **Step 2: Run test to verify it fails**

```bash
python tools/blender_exec.py tests/blender/test_housing_lug_relief.py
```

Expected: FAIL on `footprint with lug is 24.5 x 19` (still 19.0 wide) and on the relief and lug checks, plus a `KeyError: 'lug_hole_probe'`.

- [ ] **Step 3: Add relief and lug to `build_housing`**

In `models/switch_housing.py`, insert this immediately before the `body.name = "Switch_Housing"` line in `build_housing`:

```python
    # Latch relief: widen the opening by the wall-to-opening gap for
    # latch_relief_depth below the plate, on all four sides. Doing all four
    # means the switch can be inserted at any rotation.
    if h["latch_relief_depth"] > 0.0:
        relief_span = h["pocket"]      # widen out to the pocket walls
        relief = make_box(
            "Relief",
            (relief_span, relief_span, h["latch_relief_depth"]),
            (0.0, 0.0, pocket_top - h["latch_relief_depth"] / 2.0),
        )
        boolean(body, relief, "DIFFERENCE")

    # Keyring lug on -X: a flat tab with a vertical hole. Overlaps the body by
    # 0.8mm so the union has no coincident faces.
    if h["lug_protrusion"] > 0.0:
        overlap = 0.8
        tab_len = h["lug_protrusion"] + overlap
        tab_x = -(h["body_width"] / 2.0 + h["lug_protrusion"] / 2.0 - overlap / 2.0)
        tab = make_box(
            "Lug",
            (tab_len, h["lug_width"], h["lug_thickness"]),
            (tab_x, 0.0, h["height"] / 2.0),
        )
        boolean(body, tab, "UNION")

        hole = make_cylinder(
            "LugHole",
            h["lug_hole_diameter"] / 2.0,
            h["lug_thickness"] + 2.0,
            (-(h["body_width"] / 2.0 + h["lug_hole_offset"]), 0.0, h["height"] / 2.0),
            64,
        )
        boolean(body, hole, "DIFFERENCE")
```

- [ ] **Step 4: Add the lug hole probe to `housing_report`**

In `housing_report`, add this key to the returned dict, before the verdict block:

```python
        "lug_hole_probe": {
            "diameter_mm": _span_at(
                obj,
                -(h["body_width"] / 2.0 + h["lug_hole_offset"]),
                h["height"] / 2.0,
            ),
        },
```

and add this helper next to `_span`:

```python
def _span_at(obj, x, z):
    """Air span along Y through (x, *, z), sampled at 0.05mm."""
    step = 0.05
    positive = 0.0
    value = 0.0
    while value <= 6.0:
        if point_inside(obj, (x, value, z)):
            break
        positive = value
        value += step
    return round(positive * 2.0, 3)
```

- [ ] **Step 5: Run test to verify it passes**

```bash
python tools/blender_exec.py tests/blender/test_housing_lug_relief.py
```

Expected: every check `PASS`, then `ALL CHECKS PASSED`.

- [ ] **Step 6: Run the full build and confirm the report**

```bash
python tools/blender_exec.py models/switch_housing.py
```

Expected: `"VERDICT": "printable"`, `non_manifold_edges: 0`, `dimensions_mm` `[24.5, 19.0, 11.0]`, `lug_hole_probe.diameter_mm` ≈ `4.0`, `stl.size_mm` ≈ `[24.5, 19.0, 11.0]`.

- [ ] **Step 7: Commit**

```bash
git add models/switch_housing.py tests/blender/test_housing_lug_relief.py
git commit -m "feat: four-sided latch relief and vertical-axis keyring lug"
```

---

### Task 5: Snap-on bottom cap, and the matching undercut

The cap is a separate object exported to its own STL. The housing gains the undercut its tongues engage.

**Files:**
- Modify: `models/switch_housing.py` (add `build_cap`, add the undercut to `build_housing`, export both parts)
- Create: `tests/blender/test_cap.py`

**Interfaces:**
- Consumes: Task 4's `build_housing(h)`, `H`.
- Produces:
  - `build_cap(h) -> bpy.types.Object` named `Switch_Housing_Cap`.
  - `cap_report(obj, h) -> dict` with `dimensions_mm`, `mesh`, `tongue_count`, `VERDICT`.
  - `build_housing` now cuts a `h["undercut_depth"]`-deep groove into the pocket walls at `h["undercut_z"]`.
  - `main()` exports `models/switch_housing.stl` and `models/switch_housing_cap.stl`.

- [ ] **Step 1: Write the failing test**

Create `tests/blender/test_cap.py`:

```python
"""Runs inside Blender. Verifies the snap cap and the housing undercut."""

import mxgeom
import switch_housing

failures = []

def check(label, condition, detail=""):
    print(f"{'PASS' if condition else 'FAIL'}  {label}" + (f" -- {detail}" if detail else ""))
    if not condition:
        failures.append(label)

mxgeom.reset_scene()
h = dict(switch_housing.H)

cap = switch_housing.build_cap(h)
dims = [round(v, 4) for v in cap.dimensions]
check("cap footprint is 19 x 19", dims[0] == 19.0 and dims[1] == 19.0, str(dims))
check("cap is taller than its plate (tongues rise)", dims[2] > h["cap_thickness"], str(dims))

report = mxgeom.mesh_report(cap)
check("cap watertight", report["watertight"], str(report))
check("cap normals outward", report["normals_outward"], str(report))

# Plate spans z 0..1.2 and is solid; tongues rise above it near the walls.
check("cap plate is solid", mxgeom.point_inside(cap, (0.0, 0.0, 0.6)) is True)
check("cap centre is open above the plate",
      mxgeom.point_inside(cap, (0.0, 0.0, h["cap_thickness"] + 1.0)) is False)

tongue_z = h["cap_thickness"] + h["undercut_z"]
tongues = sum(
    1 for x, y in ((7.3, 0.0), (-7.3, 0.0), (0.0, 7.3), (0.0, -7.3))
    if mxgeom.point_inside(cap, (x, y, tongue_z))
)
check("four tongues present", tongues == 4, f"found {tongues}")
check("report agrees on tongue count",
      switch_housing.cap_report(cap, h)["tongue_count"] == 4)

# Housing side: the undercut must be air where the pocket wall otherwise is.
mxgeom.reset_scene()
housing = switch_housing.build_housing(h)
check("housing still watertight with undercut",
      mxgeom.mesh_report(housing)["watertight"], str(mxgeom.mesh_report(housing)))
check("undercut is air at 8.2 from centre",
      mxgeom.point_inside(housing, (8.2, 0.0, h["undercut_z"])) is False)
check("wall above the undercut is material",
      mxgeom.point_inside(housing, (8.2, 0.0, h["undercut_z"] + 2.0)) is True)
check("outer skin is not breached",
      mxgeom.point_inside(housing, (9.4, 0.0, h["undercut_z"])) is True)

print(f"\n{'ALL CHECKS PASSED' if not failures else str(len(failures)) + ' FAILED: ' + str(failures)}")
if failures:
    raise SystemExit(1)
```

- [ ] **Step 2: Run test to verify it fails**

```bash
python tools/blender_exec.py tests/blender/test_cap.py
```

Expected: FAIL with `AttributeError: module 'switch_housing' has no attribute 'build_cap'`.

- [ ] **Step 3: Cut the undercut in `build_housing`**

Insert into `build_housing`, immediately after the pocket boolean and before the opening boolean:

```python
    # Undercut the pocket walls so the cap's tongues have something to catch.
    # Reaches 17.0mm across against a 19.0mm body, so 1.0mm of outer skin is
    # left on each side and the groove never breaks through.
    if h["undercut_depth"] > 0.0:
        span = h["pocket"] + 2.0 * h["undercut_depth"]
        groove = make_box(
            "Undercut",
            (span, span, h["cap_tongue_thickness"] + 0.4),
            (0.0, 0.0, h["undercut_z"]),
        )
        boolean(body, groove, "DIFFERENCE")
```

- [ ] **Step 4: Add `build_cap` and `cap_report`**

Add to `models/switch_housing.py`:

```python
def build_cap(h):
    """Bottom cap: a plate that sits under the housing, plus four snap tongues."""
    plate = make_box(
        "Switch_Housing_Cap",
        (h["body_width"], h["body_depth"], h["cap_thickness"]),
        (0.0, 0.0, h["cap_thickness"] / 2.0),
    )

    # Tongues rise into the pocket and bulge outward at undercut_z to catch the
    # groove. Height reaches 1.2mm past the undercut so the barb has a lead-in.
    tongue_height = h["undercut_z"] + h["cap_tongue_thickness"] + 1.2
    inner_half = h["pocket"] / 2.0
    tongue_len = 6.0
    for index, (dx, dy) in enumerate(((1, 0), (-1, 0), (0, 1), (0, -1))):
        centre = inner_half - h["cap_tongue_thickness"] / 2.0
        if dx:
            size = (h["cap_tongue_thickness"], tongue_len, tongue_height)
            location = (dx * centre, 0.0, h["cap_thickness"] + tongue_height / 2.0)
        else:
            size = (tongue_len, h["cap_tongue_thickness"], tongue_height)
            location = (0.0, dy * centre, h["cap_thickness"] + tongue_height / 2.0)
        tongue = make_box(f"Tongue{index}", size, location)
        boolean(plate, tongue, "UNION")

        barb_size = (
            (h["cap_tongue_thickness"] + h["undercut_depth"], tongue_len, h["cap_tongue_thickness"])
            if dx else
            (tongue_len, h["cap_tongue_thickness"] + h["undercut_depth"], h["cap_tongue_thickness"])
        )
        barb_centre = centre + h["undercut_depth"] / 2.0
        barb_location = (
            (dx * barb_centre, 0.0, h["cap_thickness"] + h["undercut_z"])
            if dx else
            (0.0, dy * barb_centre, h["cap_thickness"] + h["undercut_z"])
        )
        barb = make_box(f"Barb{index}", barb_size, barb_location)
        boolean(plate, barb, "UNION")

    plate.name = "Switch_Housing_Cap"
    plate.data.name = "Switch_Housing_Cap"
    return plate

def cap_report(obj, h):
    tongue_z = h["cap_thickness"] + h["undercut_z"]
    tongue_count = sum(
        1 for x, y in ((7.3, 0.0), (-7.3, 0.0), (0.0, 7.3), (0.0, -7.3))
        if point_inside(obj, (x, y, tongue_z))
    )
    report = {
        "dimensions_mm": [round(v, 4) for v in obj.dimensions],
        "mesh": mesh_report(obj),
        "tongue_count": tongue_count,
    }
    mesh = report["mesh"]
    if not mesh["watertight"]:
        report["VERDICT"] = "NOT PRINTABLE - mesh is not watertight"
    elif not mesh["normals_outward"]:
        report["VERDICT"] = "NOT PRINTABLE - normals point inward"
    elif tongue_count != 4:
        report["VERDICT"] = f"NOT PRINTABLE - expected 4 tongues, found {tongue_count}"
    else:
        report["VERDICT"] = "printable"
    return report
```

- [ ] **Step 5: Export both parts from `main()`**

In `main()`, replace the single-export block:

```python
    stl = os.path.join(project, "models", "switch_housing.stl")
    export_stl(housing, stl)
    report["stl"] = verify_stl_millimetres(stl)
```

with:

```python
    stl = os.path.join(project, "models", "switch_housing.stl")
    export_stl(housing, stl)
    report["stl"] = verify_stl_millimetres(stl)

    cap = build_cap(H)
    cap_stl = os.path.join(project, "models", "switch_housing_cap.stl")
    export_stl(cap, cap_stl)
    report["cap"] = cap_report(cap, H)
    report["cap"]["stl"] = verify_stl_millimetres(cap_stl)
```

- [ ] **Step 6: Run test to verify it passes**

```bash
python tools/blender_exec.py tests/blender/test_cap.py
```

Expected: every check `PASS`, then `ALL CHECKS PASSED`.

- [ ] **Step 7: Run the full build**

```bash
python tools/blender_exec.py models/switch_housing.py
```

Expected: both `"VERDICT": "printable"`, `non_manifold_edges: 0` on each, housing `stl.size_mm` ≈ `[24.5, 19.0, 11.0]`, cap `stl.size_mm` x/y ≈ `19.0`.

- [ ] **Step 8: Commit**

```bash
git add models/switch_housing.py tests/blender/test_cap.py
git commit -m "feat: snap-on bottom cap with four barbed tongues and matching undercut"
```

---

### Task 6: Fit coupons

The plate thickness and opening size cannot be settled from specification. This builds the coupon that settles them on the printer in about four minutes.

**Files:**
- Create: `models/fit_coupons.py`
- Create: `tests/blender/test_coupons.py`

**Interfaces:**
- Consumes: `mxgeom` helpers; `switch_housing.H` for the opening and corner radius defaults.
- Produces:
  - `build_thickness_coupon(thicknesses=(1.4, 1.5, 1.6), opening=14.0, cell=20.0) -> bpy.types.Object` named `Coupon_Thickness`.
  - `build_opening_coupon(openings=(13.9, 14.0, 14.1), thickness, cell=20.0) -> bpy.types.Object` named `Coupon_Opening`.
  - Exports `models/coupon_thickness.stl`; exports `models/coupon_opening.stl` only when `KEYCAB_COUPON_THICKNESS` is set in the environment.

- [ ] **Step 1: Write the failing test**

Create `tests/blender/test_coupons.py`:

```python
"""Runs inside Blender. Verifies the fit coupons."""

import fit_coupons
import mxgeom

failures = []

def check(label, condition, detail=""):
    print(f"{'PASS' if condition else 'FAIL'}  {label}" + (f" -- {detail}" if detail else ""))
    if not condition:
        failures.append(label)

mxgeom.reset_scene()
thicknesses = (1.4, 1.5, 1.6)
coupon = fit_coupons.build_thickness_coupon(thicknesses=thicknesses, opening=14.0, cell=20.0)

dims = [round(v, 4) for v in coupon.dimensions]
check("tile is 60 x 20", dims[0] == 60.0 and dims[1] == 20.0, str(dims))
check("tile is as tall as the thickest cell", dims[2] == max(thicknesses), str(dims))

report = mxgeom.mesh_report(coupon)
check("coupon watertight", report["watertight"], str(report))
check("coupon normals outward", report["normals_outward"], str(report))

# Cells are centred at x = -20, 0, +20. Each has a 14mm hole and material at its
# own thickness only.
for index, thickness in enumerate(thicknesses):
    cx = -20.0 + index * 20.0
    check(f"cell {thickness} hole is air",
          mxgeom.point_inside(coupon, (cx, 0.0, thickness / 2.0)) is False,
          f"x={cx}")
    check(f"cell {thickness} has material beside the hole",
          mxgeom.point_inside(coupon, (cx + 8.0, 0.0, thickness / 2.0)) is True,
          f"x={cx + 8.0}")
    check(f"cell {thickness} is only {thickness} thick",
          mxgeom.point_inside(coupon, (cx + 8.0, 0.0, thickness + 0.1)) is False,
          f"probed z={thickness + 0.1}")
    check(f"cell {thickness} hole is 14 wide: air at 6.8",
          mxgeom.point_inside(coupon, (cx + 6.8, 0.0, thickness / 2.0)) is False)
    check(f"cell {thickness} hole is 14 wide: material at 7.2",
          mxgeom.point_inside(coupon, (cx + 7.2, 0.0, thickness / 2.0)) is True)

print(f"\n{'ALL CHECKS PASSED' if not failures else str(len(failures)) + ' FAILED: ' + str(failures)}")
if failures:
    raise SystemExit(1)
```

- [ ] **Step 2: Run test to verify it fails**

```bash
python tools/blender_exec.py tests/blender/test_coupons.py
```

Expected: FAIL with `ModuleNotFoundError: No module named 'fit_coupons'`.

- [ ] **Step 3: Write minimal implementation**

Create `models/fit_coupons.py`:

```python
"""Fit coupons that settle the two tolerances the spec leaves open.

Spec: docs/superpowers/specs/2026-08-10-keycap-keychain-design.md

Coupon 1 varies the plate thickness at a fixed 14.0mm opening. Coupon 2 varies
the opening at whichever thickness coupon 1 selected, and is only needed if
every cell of coupon 1 is uniformly loose or uniformly tight.
"""

import json
import os

import bpy

import mxgeom
from mxgeom import (
    boolean, export_stl, make_box, make_loft, mesh_report, reset_scene,
    rounded_rect, verify_stl_millimetres,
)

CORNER_R = 0.5
CORNER_SEGMENTS = 8
LABEL_DEPTH = 0.4

def _cell(name, cell, thickness, opening, centre_x):
    """One coupon cell: a plate of `thickness` with a rounded-square opening."""
    tile = make_box(name, (cell, cell, thickness), (centre_x, 0.0, thickness / 2.0))
    outline = rounded_rect(opening, opening, CORNER_R, CORNER_SEGMENTS)
    shifted = [(x + centre_x, y) for x, y in outline]
    cutter = make_loft(f"{name}_Cut", shifted, -1.0, shifted, thickness + 1.0)
    boolean(tile, cutter, "DIFFERENCE")
    return tile

def _emboss_bars(target, count, thickness, centre_x, cell):
    """Mark a cell with `count` raised bars, readable without text rendering."""
    for index in range(count):
        bar = make_box(
            f"Bar_{centre_x}_{index}",
            (1.2, 4.0, LABEL_DEPTH),
            (centre_x - cell / 2.0 + 2.5 + index * 2.0,
             -cell / 2.0 + 3.0,
             thickness + LABEL_DEPTH / 2.0),
        )
        boolean(target, bar, "UNION")

def build_thickness_coupon(thicknesses=(1.4, 1.5, 1.6), opening=14.0, cell=20.0):
    """Flat tile of cells, one per candidate plate thickness."""
    tile = None
    for index, thickness in enumerate(thicknesses):
        centre_x = (index - (len(thicknesses) - 1) / 2.0) * cell
        piece = _cell(f"Cell{index}", cell, thickness, opening, centre_x)
        _emboss_bars(piece, index + 1, thickness, centre_x, cell)
        if tile is None:
            tile = piece
        else:
            boolean(tile, piece, "UNION")
    tile.name = "Coupon_Thickness"
    tile.data.name = "Coupon_Thickness"
    return tile

def build_opening_coupon(thickness, openings=(13.9, 14.0, 14.1), cell=20.0):
    """Flat tile of cells, one per candidate opening size, at one thickness."""
    tile = None
    for index, opening in enumerate(openings):
        centre_x = (index - (len(openings) - 1) / 2.0) * cell
        piece = _cell(f"OCell{index}", cell, thickness, opening, centre_x)
        _emboss_bars(piece, index + 1, thickness, centre_x, cell)
        if tile is None:
            tile = piece
        else:
            boolean(tile, piece, "UNION")
    tile.name = "Coupon_Opening"
    tile.data.name = "Coupon_Opening"
    return tile

def _verdict(report):
    if not report["mesh"]["watertight"]:
        return "NOT PRINTABLE - mesh is not watertight"
    if not report["mesh"]["normals_outward"]:
        return "NOT PRINTABLE - normals point inward"
    return "printable"

def main():
    project = os.environ.get(
        "KEYCAB_PROJECT", r"C:\Users\user\orca\projects\keycab-3dprint"
    )
    reset_scene()
    scene = bpy.context.scene
    scene.unit_settings.system = "METRIC"
    scene.unit_settings.scale_length = 0.001
    scene.unit_settings.length_unit = "MILLIMETERS"

    out = {}

    thicknesses = (1.4, 1.5, 1.6)
    coupon = build_thickness_coupon(thicknesses=thicknesses)
    entry = {
        "cells": [{"bars": i + 1, "thickness_mm": t} for i, t in enumerate(thicknesses)],
        "dimensions_mm": [round(v, 4) for v in coupon.dimensions],
        "mesh": mesh_report(coupon),
    }
    entry["VERDICT"] = _verdict(entry)
    path = os.path.join(project, "models", "coupon_thickness.stl")
    export_stl(coupon, path)
    entry["stl"] = verify_stl_millimetres(path)
    out["coupon_thickness"] = entry

    chosen = os.environ.get("KEYCAB_COUPON_THICKNESS")
    if chosen:
        reset_scene()
        openings = (13.9, 14.0, 14.1)
        second = build_opening_coupon(float(chosen), openings=openings)
        entry2 = {
            "chosen_thickness_mm": float(chosen),
            "cells": [{"bars": i + 1, "opening_mm": o} for i, o in enumerate(openings)],
            "dimensions_mm": [round(v, 4) for v in second.dimensions],
            "mesh": mesh_report(second),
        }
        entry2["VERDICT"] = _verdict(entry2)
        path2 = os.path.join(project, "models", "coupon_opening.stl")
        export_stl(second, path2)
        entry2["stl"] = verify_stl_millimetres(path2)
        out["coupon_opening"] = entry2
    else:
        out["coupon_opening"] = "skipped - set KEYCAB_COUPON_THICKNESS to build it"

    print("COUPON_REPORT_START")
    print(json.dumps(out, indent=2))
    print("COUPON_REPORT_END")

if __name__ == "__blender_mcp__":
    main()
```

- [ ] **Step 4: Run test to verify it passes**

```bash
python tools/blender_exec.py tests/blender/test_coupons.py
```

Expected: every check `PASS`, then `ALL CHECKS PASSED`.

- [ ] **Step 5: Build the coupon STL**

```bash
python tools/blender_exec.py models/fit_coupons.py
```

Expected: `coupon_thickness.VERDICT` is `printable`, `stl.size_mm` ≈ `[60.0, 20.0, 2.0]` (1.6 plate + 0.4 emboss), `coupon_opening` reported as skipped. The cell with 1 bar is 1.4 mm, 2 bars is 1.5 mm, 3 bars is 1.6 mm.

- [ ] **Step 6: Commit**

```bash
git add models/fit_coupons.py tests/blender/test_coupons.py
git commit -m "feat: plate-thickness and opening fit coupons"
```

---

### Task 7: Reusable slicing script

The working slice invocation currently exists only as an ad-hoc shell command. Capture it, including the two corrections that were needed to make it produce a fast, correctly-heated print, so the housing, cap and coupons can each be sliced repeatably.

**Files:**
- Create: `tools/slice_part.ps1`
- Modify: `README.md` (add a "Slicing and printing" section)

**Interfaces:**
- Consumes: `tools/flatten_orca_preset.py` (existing), the OrcaSlicer portable install at `C:\Users\user\AppData\Local\Programs\OrcaSlicer-portable`.
- Produces: `tools/slice_part.ps1 -Stl <path> -Out <name.gcode.3mf> [-Process <preset>] [-Filament <preset>] [-BedType <type>] [-BrimWidth <mm>]` writing into `gcode/`, and echoing layer count, wall speed, bed temperature, support flag, estimated time and grams.

- [ ] **Step 1: Write the failing test**

There is no unit-test harness for PowerShell here, so the test is the script's own self-check on a known input. Run:

```bash
powershell -File tools/slice_part.ps1 -Stl models/coupon_thickness.stl -Out coupon_thickness.gcode.3mf
```

Expected before implementation: `The term 'tools/slice_part.ps1' is not recognized`.

- [ ] **Step 2: Write the implementation**

Create `tools/slice_part.ps1`:

```powershell
<#
.SYNOPSIS
  Slice one STL for the Bambu Lab A1 mini with the vendor's real high-speed values.

.NOTES
  Two corrections are baked in because both silently ruin a print:

  1. OrcaSlicer's bundled presets are `inherits` deltas. Passing a leaf process
     JSON to --load-settings loads only the delta and falls back to built-in
     defaults -- 0.2mm layers at 60mm/s instead of the vendor's 0.28mm at
     200mm/s. tools/flatten_orca_preset.py resolves the chain first. The MACHINE
     preset must stay the un-flattened leaf; the CLI rejects a flattened one.
  2. --curr-bed-type must be passed explicitly. The default is "Cool Plate",
     which commands a 35C bed; PLA on the A1 mini's textured PEI plate needs 65C.
#>
[CmdletBinding()]
param(
  [Parameter(Mandatory = $true)][string]$Stl,
  [Parameter(Mandatory = $true)][string]$Out,
  [string]$Process  = "0.28mm Extra Draft @BBL A1M",
  [string]$Filament = "Generic PLA High Speed @BBL A1M",
  [string]$Machine  = "Bambu Lab A1 mini 0.4 nozzle",
  [string]$BedType  = "Textured PEI Plate",
  [double]$BrimWidth = 3,
  [string]$OrcaDir  = "C:\Users\user\AppData\Local\Programs\OrcaSlicer-portable"
)

$ErrorActionPreference = 'Stop'

$root    = Split-Path -Parent $PSScriptRoot
$outDir  = Join-Path $root 'gcode'
$flatDir = Join-Path $outDir '_presets'
$profiles = Join-Path $OrcaDir 'resources\profiles'
$exe      = Join-Path $OrcaDir 'orca-slicer.exe'

foreach ($p in @($exe, $profiles, $Stl)) {
  if (-not (Test-Path $p)) { throw "not found: $p" }
}
foreach ($d in @($outDir, $flatDir)) {
  if (-not (Test-Path $d)) { New-Item -ItemType Directory -Path $d | Out-Null }
}

python (Join-Path $PSScriptRoot 'flatten_orca_preset.py') $profiles 'BBL' `
  --machine $Machine --process $Process --filament $Filament --outdir $flatDir
if ($LASTEXITCODE -ne 0) { throw "preset flattening failed" }

$leafMachine = Join-Path $profiles "BBL\machine\$Machine.json"
if (-not (Test-Path $leafMachine)) { throw "machine preset not found: $leafMachine" }

$stlFull = (Resolve-Path $Stl).Path
$argStr =
  '--load-settings "' + $leafMachine + ';' + (Join-Path $flatDir 'process.json') + '"' +
  ' --load-filaments "' + (Join-Path $flatDir 'filament.json') + '"' +
  ' --curr-bed-type "' + $BedType + '"' +
  ' --slice 0 --brim-type outer_only --brim-width ' + $BrimWidth +
  ' --ensure-on-bed --export-3mf "' + $Out + '"' +
  ' --outputdir "' + $outDir + '" "' + $stlFull + '"'

$stdout = Join-Path $outDir '_slice.out.log'
$stderr = Join-Path $outDir '_slice.err.log'
Set-Content -Path $stdout -Value '' -Encoding utf8
Set-Content -Path $stderr -Value '' -Encoding utf8

$proc = Start-Process -FilePath $exe -ArgumentList $argStr `
  -RedirectStandardOutput $stdout -RedirectStandardError $stderr `
  -PassThru -NoNewWindow -Wait

if ($proc.ExitCode -ne 0) {
  Write-Output "SLICE FAILED (exit $($proc.ExitCode))"
  Get-Content $stdout; Get-Content $stderr
  exit 1
}

$gcode = Join-Path $outDir 'plate_1.gcode'
if (-not (Test-Path $gcode)) { throw "slicer produced no plate_1.gcode" }

Write-Output "sliced -> $(Join-Path $outDir $Out)"
Write-Output '--- verify before printing ---'
Select-String -Path $gcode -Pattern '^; (total layer number|layer_height =|outer_wall_speed|nozzle_temperature =|curr_bed_type|enable_support|brim_width|printer_model)' |
  ForEach-Object { '  ' + $_.Line }
Select-String -Path $gcode -Pattern '^(M190)' | Select-Object -First 1 |
  ForEach-Object { '  ' + $_.Line }
Select-String -Path $gcode -Pattern '(model printing time|filament used \[g\])' |
  Where-Object { $_.Line -match '^;' } | ForEach-Object { '  ' + $_.Line.Trim() }
```

- [ ] **Step 3: Run it and check the header**

```bash
powershell -File tools/blender_server.ps1 status
powershell -File tools/slice_part.ps1 -Stl models/coupon_thickness.stl -Out coupon_thickness.gcode.3mf
```

Expected in the verify block: `layer_height = 0.28`, `outer_wall_speed = 200`, `curr_bed_type = Textured PEI Plate`, `M190 S65`, `enable_support = 0`, `printer_model = Bambu Lab A1 mini`, plus a time and a gram figure. **If `layer_height` reads 0.2 or `outer_wall_speed` reads 60, the preset chain did not resolve — do not print it.**

- [ ] **Step 4: Slice the housing and the cap**

```bash
powershell -File tools/slice_part.ps1 -Stl models/switch_housing.stl -Out switch_housing.gcode.3mf
powershell -File tools/slice_part.ps1 -Stl models/switch_housing_cap.stl -Out switch_housing_cap.gcode.3mf
```

Expected: both report `enable_support = 0`. The housing STL is already plate-face-down because `build_housing` puts the plate at the top and the slicer does not flip it — confirm `stl.size_mm` z is `11.0` and that the reported time is single-digit minutes.

- [ ] **Step 5: Document it**

Add to `README.md`, after the "Everyday use" section:

```markdown
## Slicing and printing

```powershell
powershell -File tools\slice_part.ps1 -Stl models\switch_housing.stl -Out switch_housing.gcode.3mf
python tools\bambu_print.py   # needs BAMBU_HOST / BAMBU_SERIAL / BAMBU_CODE / BAMBU_FILE
```

Two settings silently ruin a print if left at their defaults, so `slice_part.ps1`
sets both and prints them back for checking:

- **Preset inheritance.** OrcaSlicer's bundled presets are `inherits` deltas.
  Handing a leaf process JSON to `--load-settings` loads the delta only and falls
  back to built-in defaults — 0.2 mm layers at 60 mm/s rather than the vendor's
  0.28 mm at 200 mm/s. `tools/flatten_orca_preset.py` resolves the chain first.
  The machine preset must stay un-flattened; the CLI rejects a flattened one.
- **Bed type.** The default is `Cool Plate`, which commands a 35 °C bed. PLA on
  the A1 mini's textured PEI plate needs 65 °C, and at 35 °C a small part with
  little contact area will let go.
```

- [ ] **Step 6: Commit**

```bash
git add tools/slice_part.ps1 README.md
git commit -m "feat: reusable slicing script with preset flattening and bed type"
```

---

## Post-implementation: settle the tolerances on the printer

Not code, but the plan is not finished without it. In order:

1. Print `coupon_thickness.gcode.3mf` (~4 min). Try the switch in all three cells.
2. Set `H["plate_thickness"]` in `models/switch_housing.py` to the cell that latches with a clean click, then rebuild and re-slice.
3. If all three cells are uniformly loose or tight, build coupon 2 with
   `KEYCAB_COUPON_THICKNESS=<best>` and repeat for the opening, then set `H["opening"]`.
4. Print the housing and cap. Expect one or two iterations on `H["undercut_depth"]`
   from its 0.6 mm starting value: a cap that falls off wants more, a tongue that
   snaps wants less.

---

## Self-Review

**1. Spec coverage**

| Spec section | Task |
| --- | --- |
| Closed box housing, all dimensions | 3, 4 |
| Two-piece retention: 1.5 mm plate + MX latches | 3 (plate/opening), 4 (relief) |
| Removable snap bottom cap, undercut 0.6 @ 1.5 | 5 |
| Keyring lug, vertical hole axis | 4 |
| No individual pin holes (flat pocket floor) | 3 — pocket is a plain box difference |
| Click travel (nothing above plate level) | 3 — asserted by `plate is solid at the edge` plus the absence of any geometry above `height` |
| Coupon 1 (thickness) and coupon 2 (opening) | 6 |
| Verification: watertight, normals, ray-cast thickness, ASCII sections, lug hole, STL bbox | 3, 4, 5, 6 |
| Print orientation, no support | 7 |
| Out of scope items | not implemented, as intended |

Gap found and closed: the spec's shared-helper reuse was implicit; Tasks 1 and 2 exist because `keycap.py`'s helpers are unimportable as-is.

**2. Placeholder scan** — no `TBD`/`TODO`/"handle edge cases"/"similar to Task N". Every code step carries real code. Coupon 2 is conditional on a stated trigger, not deferred.

**3. Type consistency** — `H` keys are spelled identically in Tasks 3, 4, 5 and the post-implementation notes. `build_housing`/`build_cap`/`housing_report`/`cap_report`/`build_thickness_coupon`/`build_opening_coupon` are used with the signatures declared in their Interfaces blocks. `cross_sections` takes `(obj, half_extent, heights, step)` everywhere after Task 2, including the updated `keycap.py` call site. `_span(obj, z, axis)` and `_span_at(obj, x, z)` are distinct helpers with distinct signatures.

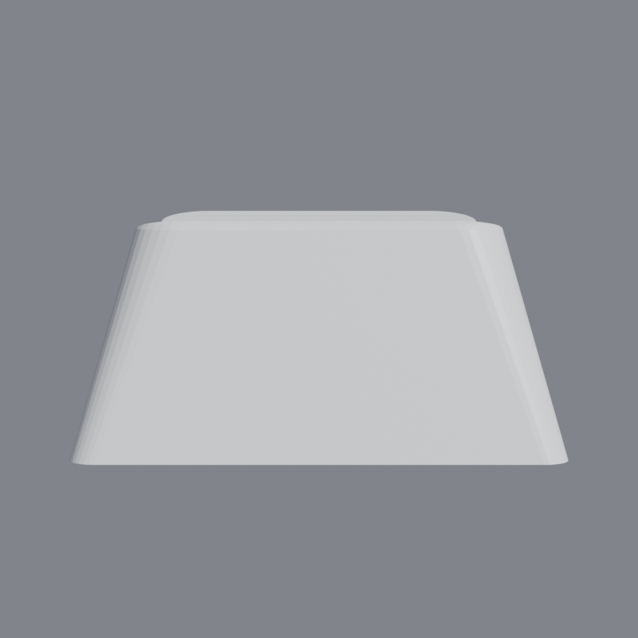
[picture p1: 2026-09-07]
renders/keycap_front.png

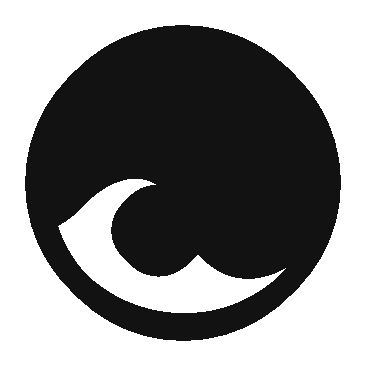
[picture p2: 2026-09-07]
renders/wave_variants/C_fill_rank0.png

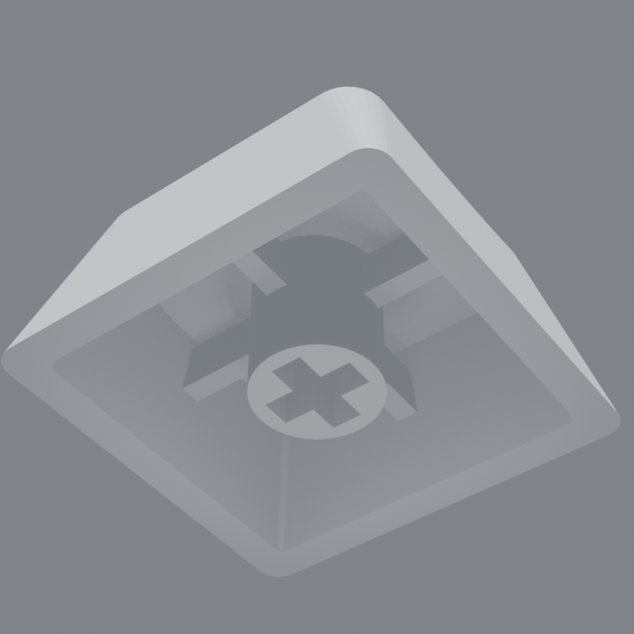
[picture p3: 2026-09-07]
renders/keycap_bottom.png

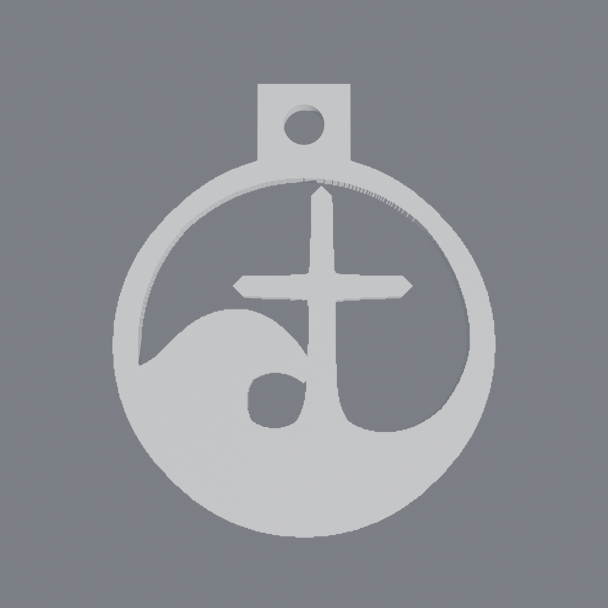
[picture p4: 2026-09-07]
renders/keyring_top.png

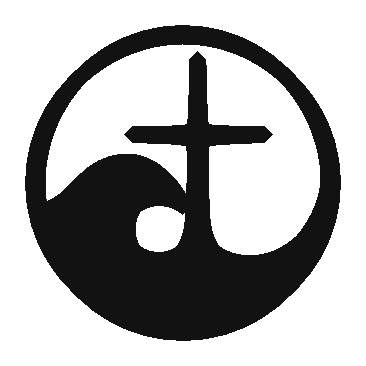
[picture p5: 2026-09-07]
renders/wave_variants/B_fill_rank1.png

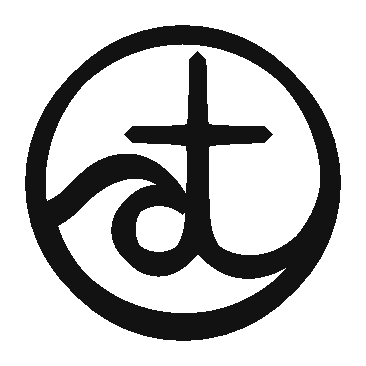
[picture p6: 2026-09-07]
renders/wave_variants/A_nothing_filled.png

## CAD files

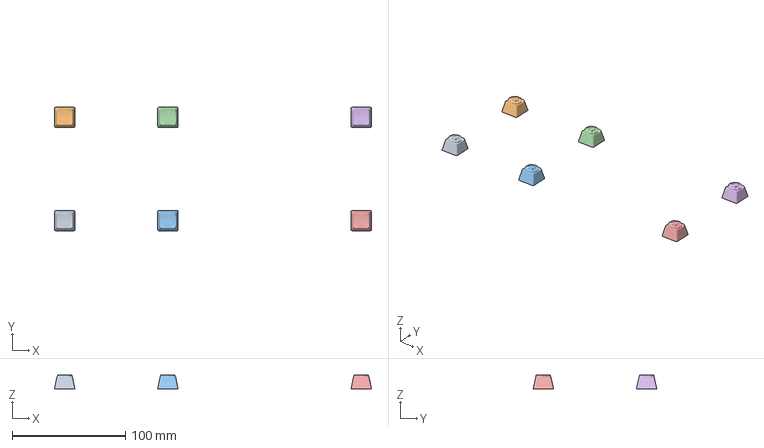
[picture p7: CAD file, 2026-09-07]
gcode/seq_probe_6.gcode.3mf
279.5 x 109.0 x 12.0 mm
keycap_1u_r3_logo_v4.stl x 6

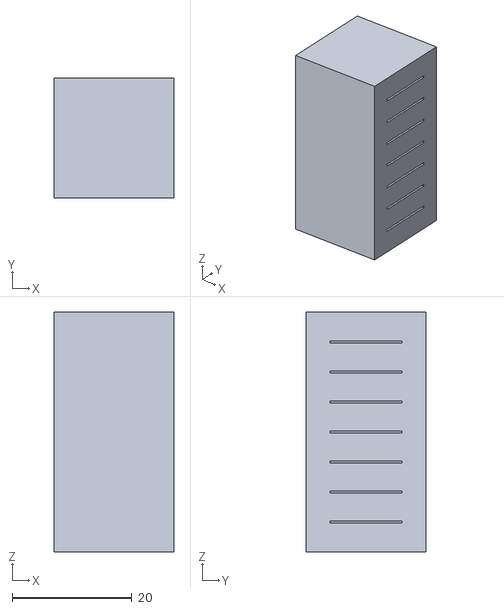
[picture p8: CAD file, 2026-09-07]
models/z_test_cube_40mm.stl
20.0 x 20.0 x 40.0

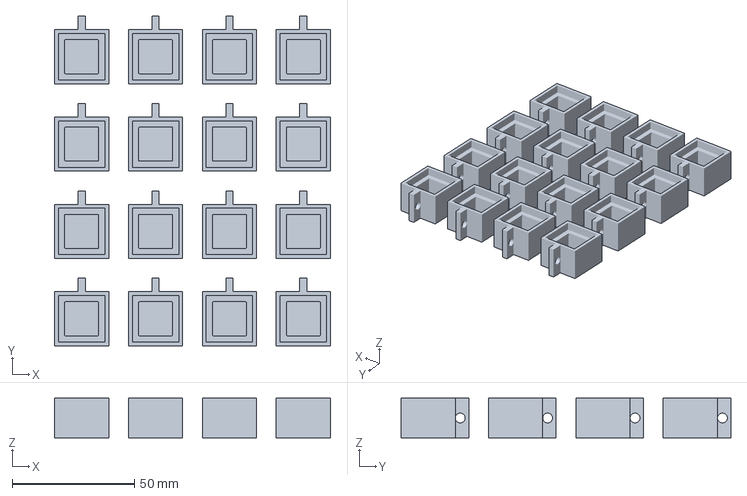
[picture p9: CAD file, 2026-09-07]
gcode/housing_4x4_220_028_nobrim.gcode.3mf
112.8 x 134.8 x 16.2 mm

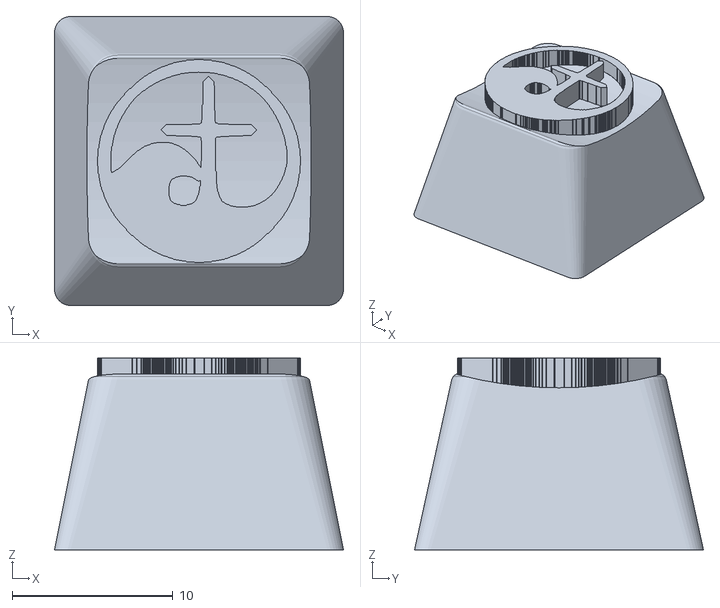
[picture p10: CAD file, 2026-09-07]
models/keycap_1u_r3_logo_v4.stl
18.0 x 18.0 x 12.0

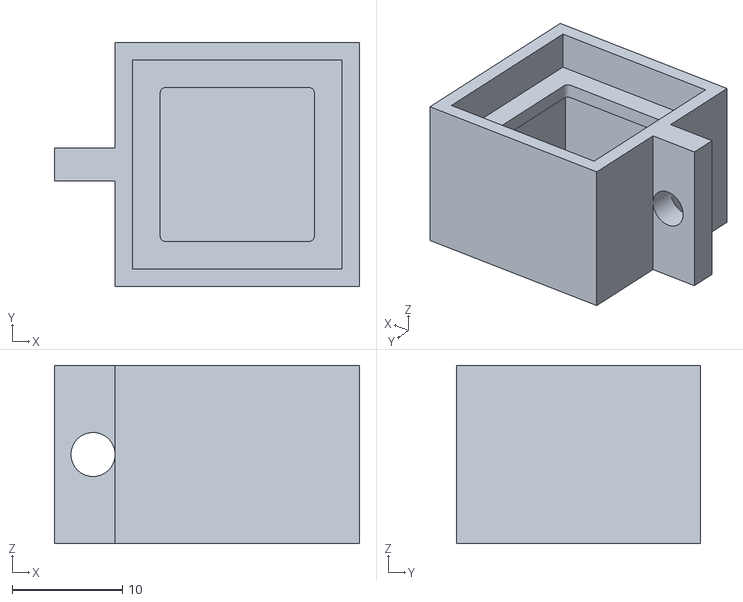
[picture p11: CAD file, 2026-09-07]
models/switch_housing_fin.stl
27.7 x 22.2 x 16.2

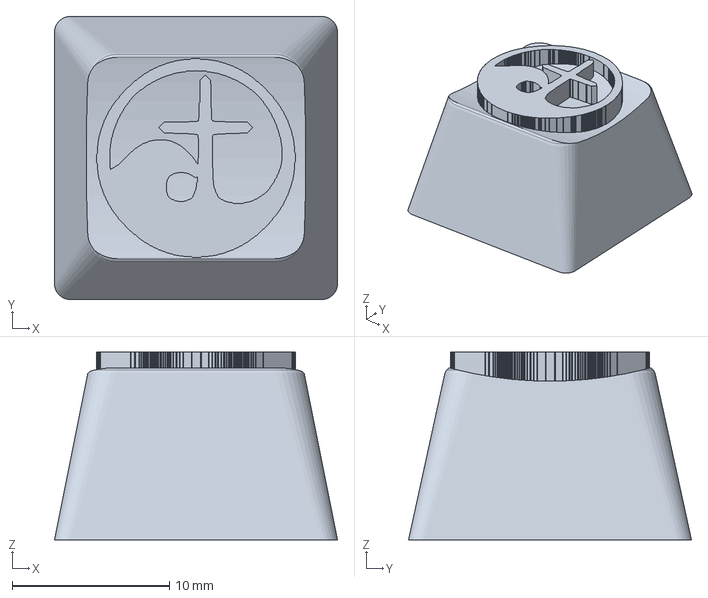
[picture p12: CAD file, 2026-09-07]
gcode/keycap_logo_v4_220.gcode.3mf
18.0 x 18.0 x 12.0 mm

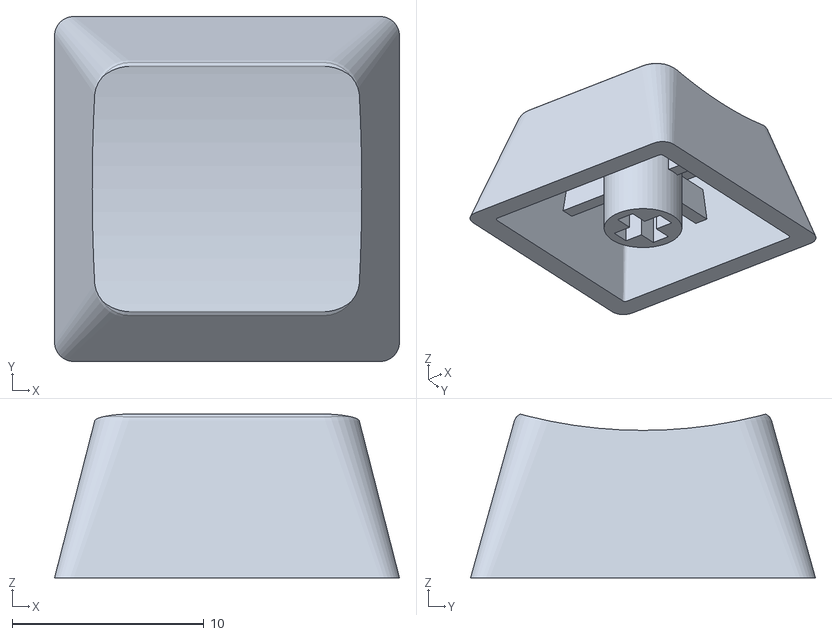
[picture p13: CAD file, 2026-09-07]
models/keycap_1u_r3.stl
18.0 x 18.0 x 8.55

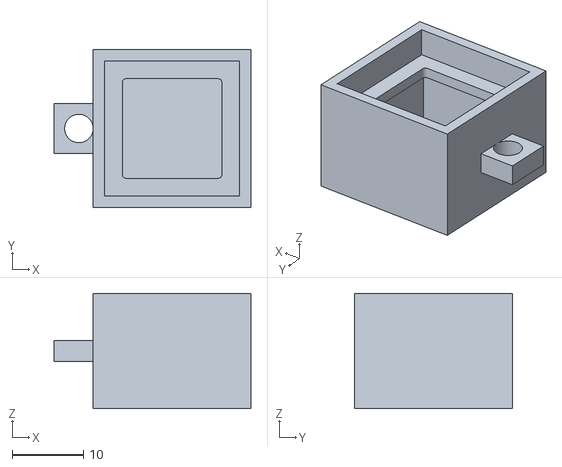
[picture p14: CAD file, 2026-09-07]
models/switch_housing.stl
27.7 x 22.2 x 16.2

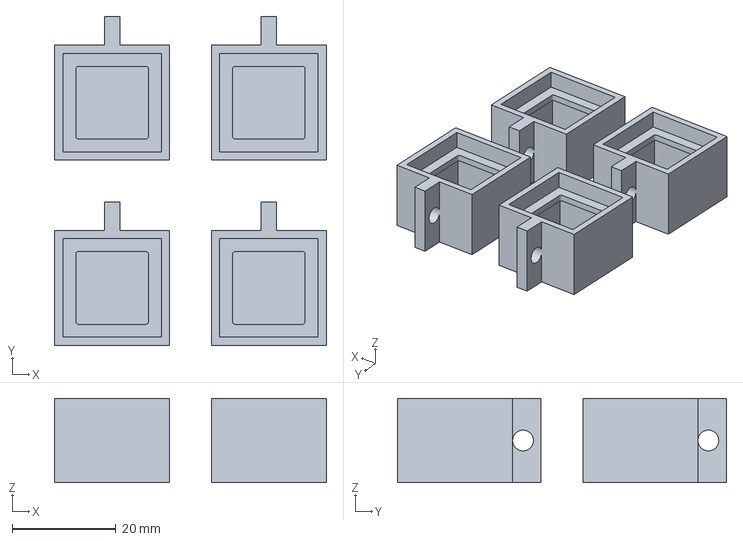
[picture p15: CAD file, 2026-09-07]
gcode/housing_2x2_220_028.gcode.3mf
52.4 x 63.4 x 16.2 mm

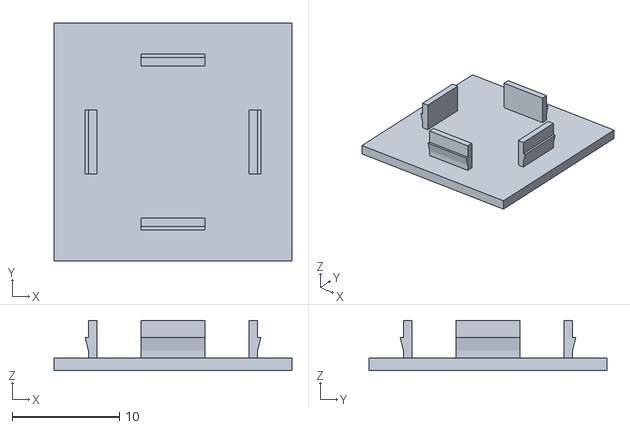
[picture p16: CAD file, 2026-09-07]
models/switch_housing_cap.stl
22.2 x 22.2 x 4.70

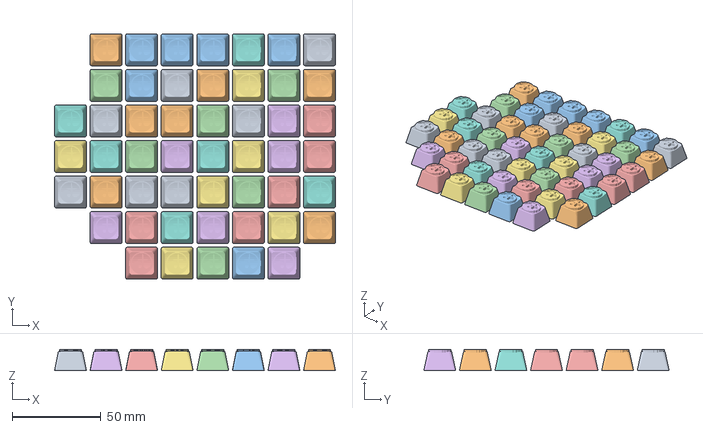
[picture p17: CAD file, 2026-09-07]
gcode/keycap_logo_x50_020.gcode.3mf
158.0 x 138.0 x 12.0 mm
keycap_1u_r3_logo.stl x 50

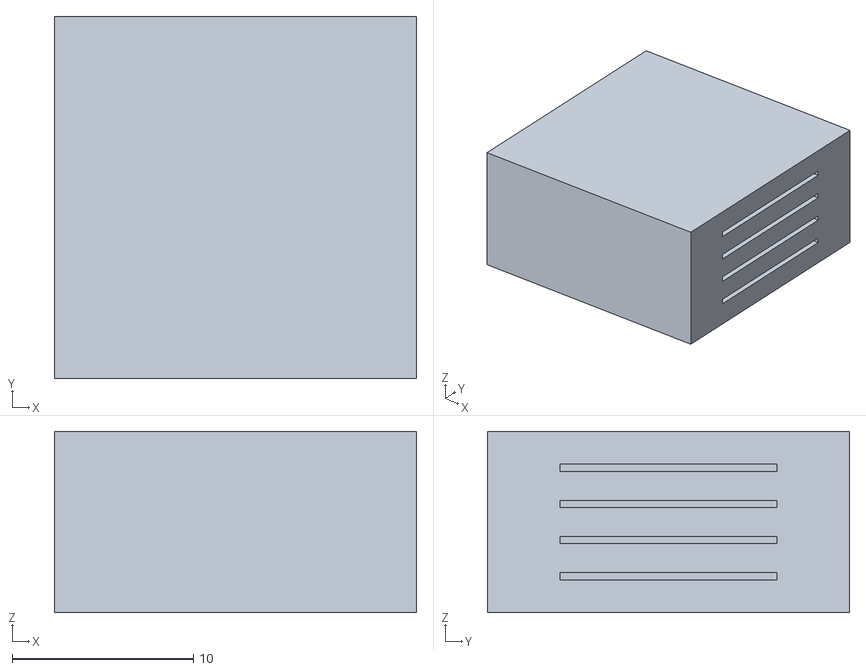
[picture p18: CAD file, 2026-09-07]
models/z_test_cube.stl
20.0 x 20.0 x 10.0

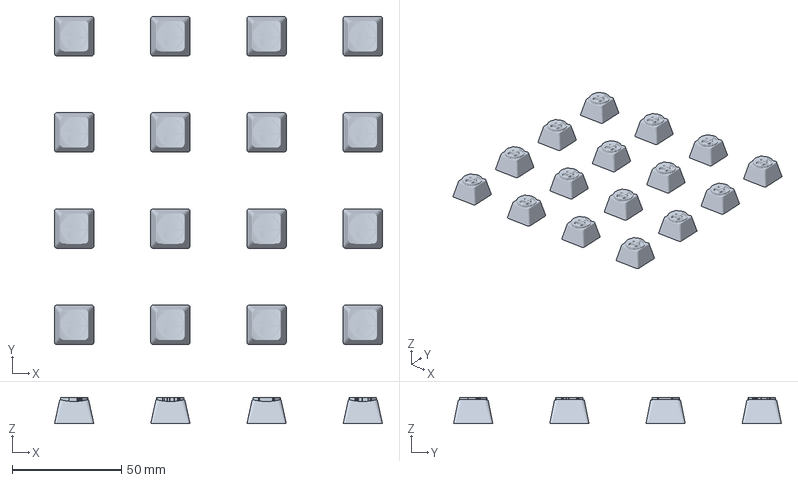
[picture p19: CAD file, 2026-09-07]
gcode/v4_4x4_far_205_012.gcode.3mf
150.0 x 150.0 x 12.0 mm

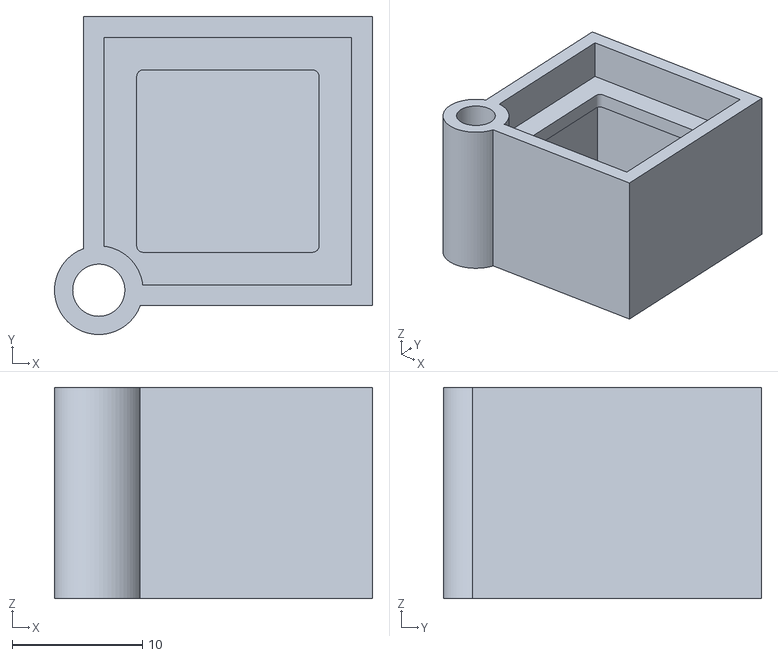
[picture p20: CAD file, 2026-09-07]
models/switch_housing_corner.stl
24.4 x 24.4 x 16.2

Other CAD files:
gcode/z_test_40mm_fast.gcode.3mf
models/keycap_1u_r3_logo_v3_APPROVED.stl
gcode/keycap_logo_x50_028.gcode.3mf
models/housing_plate_2x2.stl
gcode/housing_4x4_220_028.gcode.3mf
gcode/housing_bezel_210.gcode.3mf
gcode/housing_fast_220_028.gcode.3mf
gcode/housing_fin_x16_210_028.gcode.3mf
gcode/housing_fin_x16_220_028_proven.gcode.3mf
gcode/housing_fin_x9_210_028.gcode.3mf
gcode/housing_onepiece_220.gcode.3mf
gcode/keycap_1u_r3.gcode.3mf
gcode/keycap_1u_r3_logo_v3_APPROVED_220C_012mm.gcode.3mf
gcode/keycap_A.gcode.3mf
gcode/keycap_logo.gcode.3mf
gcode/keycap_logo_v2.gcode.3mf
gcode/keycap_logo_v3.gcode.3mf
gcode/keycap_logo_v3_210.gcode.3mf
gcode/keycap_logo_x25_012.gcode.3mf
gcode/keycap_logo_x50.gcode.3mf
gcode/keycap_logo_x50_016.gcode.3mf
gcode/keycap_taper_220_012.gcode.3mf
gcode/keycap_textured.gcode.3mf
gcode/keycap_v3_220_012.gcode.3mf
gcode/keychain_both.gcode.3mf
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
